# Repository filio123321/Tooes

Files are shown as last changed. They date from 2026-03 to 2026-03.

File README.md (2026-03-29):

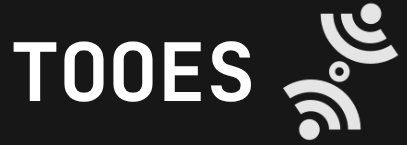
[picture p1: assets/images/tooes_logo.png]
TOOES
# 

Tooes is a Raspberry Pi-based passive RF navigation prototype. The firmware
listens to broadcast cellular signals, resolves observed towers against a local
OpenCellID database, and fuses the RF fixes with IMU dead-reckoning to track
position on a small e-paper map display.

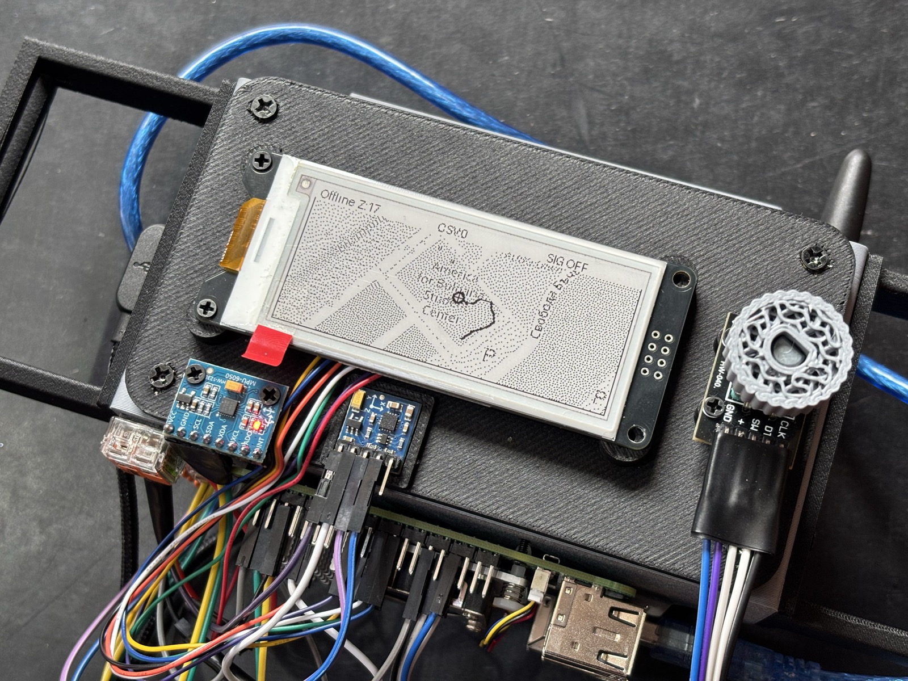
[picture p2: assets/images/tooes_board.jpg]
A photo of the TOOES project build


## What The Repo Does Today

- The main app starts from a known GPS coordinate (`INITIAL_L`), tracks
  short-range movement with the MPU-6050 accelerometer and QMC5883L
  magnetometer, and blends in periodic SDR-based position fixes as the user
  moves. The fused path is rendered live on the e-paper display.
- A walking sweep POC performs 2D dead-reckoning from accelerometer data and
  magnetometer heading and visualises the path and RSSI bars in a desktop
  Pygame window. It does not use the MPU-6050 gyroscope.
- The radio path implements the GSM `grgsm_scanner` flow. LTE protocol-specific
  work can be added later without changing the top-level documentation
  structure.

## Documentation

- [System architecture](docs/architecture.md)
- [Hardware and wiring](docs/hardware.md)
- [Motion estimation math](docs/algorithms/motion-estimation.md)
- [RF localization pipeline](docs/algorithms/rf-localization.md)
- [Raspberry Pi setup and operations](docs/operations/pi-setup.md)
- [Experiments and proof-of-concepts](docs/experiments.md)
- [Firmware-specific reference](firmware/README.md)

## Repository Layout

- `firmware/` — Raspberry Pi firmware: HAL, navigation engine, runtime
  orchestrator, UI, scripts, and tests.
- `firmware/navigation/` — navigation engine: IMU sample processing, SDR fix
  blending, trace logging, and configuration.
- `firmware/runtime/` — background threading: orchestrator and navigation
  worker that feed the UI.
- `signal_processing/` — SDR positioning algorithms (trilateration, Kalman
  filter, RF-IMU fusion). Experimental.
- `scripts/` — repo-level utilities including the Pi setup script.
- `external/waveshare-epd/` — Waveshare e-paper driver submodule.
- `assets/` — 3D-printable hardware assets.
- `separate_component_files/` — standalone experiments and component-specific
  utilities.

## Quick Start

### 1. Run the test suite

```bash
python -m pytest firmware/tests/ -v
```

### 2. Exercise the mock or replay RF path without Pi hardware

```bash
HAL_BACKEND=replay HAL_REPLAY_PATH=firmware/tests/fixtures/golden_sweep.jsonl \
python -c "from firmware.hal import get_sweep_source; print(list(get_sweep_source())[:2])"
```

### 3. Deploy and run on the Raspberry Pi

See [docs/operations/pi-setup.md](docs/operations/pi-setup.md) for the full
guide. The short version:

```bash
# From your laptop — syncs code, configures I2C, sets up git for future pulls:
PI_PASS=<password> bash scripts/setup_pi.sh [user@host]

# Then on the Pi — install dependencies and set your starting location:
pip3 install --break-system-packages -r firmware/requirements.txt

cat > .env.local <<'EOF'
INITIAL_L=42.012280,23.095261
EOF

# Launch the app:
HAL_BACKEND=grgsm \
HAL_ROTATION=qmc5883l \
HAL_ACCEL=mpu6050 \
HAL_GRGSM_SCANNER_CMD="grgsm_scanner -b GSM900 -a 'driver=sdrplay'" \
python3 -m firmware.run
```

`INITIAL_L` is the absolute starting point used by the navigation engine. The
app then tracks IMU-based relative movement locally and periodically blends in
SDR fixes as it moves away from the last anchor.

While running, the fused path is written to
`firmware/logs/navigation_trace_*.jsonl` unless you set
`NAV_PATH_LOG_ENABLED=false`.

## Required Runtime Assets

- `external/waveshare-epd/` must be populated with
  `git submodule update --init --recursive` before the e-paper display path
  can import the Waveshare driver.
- `firmware/data/<mcc>.csv` must exist locally for any country code you want
  to resolve through OpenCellID. These files are intentionally not committed.
- `firmware/offline_tiles/` is optional but required for the map view to
  render real offline tiles instead of placeholders.

## Important Notes

- The absolute position estimate in the main app is not true trilateration.
  The current implementation is a heuristic RSSI-weighted centroid over the
  resolved towers, used as a periodic correction anchor for the IMU track.
- The motion stack is currently accelerometer plus magnetometer; gyroscope
  fusion is not yet implemented.
- The repo contains both product code and experiments. See
  [docs/experiments.md](docs/experiments.md) for the current boundary.

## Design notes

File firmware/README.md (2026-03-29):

# firmware/

Firmware-specific reference for the Raspberry Pi application, HAL backends, and
supporting scripts.

For project-wide documentation, start at:

- `README.md`
- `docs/architecture.md`
- `docs/algorithms/motion-estimation.md`
- `docs/algorithms/rf-localization.md`

Python code that runs on the Raspberry Pi (or a laptop during development):
GSM cell observation via `grgsm_scanner` + SoapySDR, OpenCellID tower lookup,
IMU dead-reckoning with SDR fix blending, and e-ink display output.

## Project structure

```
firmware/
├── hal/                       # Hardware Abstraction Layer
│   ├── __init__.py            # Public API: protocols, types, factory getters
│   ├── types.py               # CellKey, SweepSample dataclasses + JSON (de)serialization
│   ├── protocols.py           # SweepSampleSource, RotationReader, CellRssiReader,
│   │                          #   TiltReader, AccelerationReader, DisplaySink
│   ├── mock.py                # MockSweepSource — deterministic synthetic sweep
│   ├── mock_cells.py          # MockCellRssiReader — position-dependent fake RSSI
│   ├── replay.py              # JsonlReplaySource — replay a recorded .jsonl sweep file
│   ├── grgsm_scanner.py       # Parse grgsm_scanner stdout, GrgsmCellReader adapter
│   ├── factory.py             # Env-driven factories: get_sweep_source(), get_rotation_reader(),
│   │                          #   get_tilt_reader(), get_accel_reader(), get_cell_reader()
│   ├── dead_reckoning.py      # DeadReckoningTracker — ZUPT-based position tracking
│   ├── qmc5883l.py            # QMC5883L magnetometer RotationReader (real hardware, I2C)
│   ├── mpu6050.py             # MPU-6050 TiltReader + AccelerationReader (I2C)
│   └── _stub_rotation.py     # Stubs: StubRotationReader, StubTiltReader, StubAccelerationReader
│
├── navigation/                # Navigation engine (IMU + SDR fusion)
│   ├── config.py              # NavigationConfig — loads .env.local and env vars
│   ├── service.py             # NavigationEngine — fuses IMU + SDR, emits NavigationSnapshot
│   ├── imu.py                 # ImuSampleProcessor — step detection + dead-reckoning
│   ├── sdr.py                 # SdrFixProvider — schedules SDR fixes, computes confidence
│   ├── geo.py                 # Distance and bearing helpers
│   ├── path_logger.py         # Writes navigation trace to JSONL
│   └── trace.py               # In-memory trace point history
│
├── runtime/                   # Background threading and orchestration
│   ├── orchestrator.py        # FirmwareOrchestrator — owns sensor threads, exposes snapshot()
│   └── navigation_worker.py   # Navigation update loop running at IMU_UPDATE_HZ
│
├── ui/                        # E-ink display UI
│   ├── app.py                 # Entry point — inits display, encoder, button; runs event loop
│   ├── runtime.py             # Bridges app.py with FirmwareOrchestrator
│   ├── state.py               # UiState, RuntimeSnapshot, DiscoveredTower dataclasses
│   ├── screens.py             # Screen renderers: BOOT, TUTORIAL, SCANNING, MAP
│   ├── redraw.py              # Decides when a full e-paper refresh is needed
│   ├── geo.py                 # Geographic utilities (zoom, coordinate clamping)
│   ├── tiles.py               # Offline OSM tile rendering
│   └── icons.py               # UI icon definitions
│
├── tests/
│   ├── fixtures/
│   │   └── golden_sweep.jsonl # 20-sample fixture generated from MockSweepSource
│   ├── test_hal.py            # pytest suite for the HAL
│   ├── test_navigation.py     # pytest suite for the navigation engine
│   └── test_ui_redraw.py      # pytest suite for redraw logic
│
├── data/
│   └── 284.csv                # OpenCellID tower database for MCC 284 (Bulgaria)
│
├── logs/                      # Navigation trace logs (gitignored, created at runtime)
│
├── scripts/
│   ├── orientation_cube.py    # 3D cube visualisation of sensor orientation (Pi desktop)
│   ├── sweep_poc.py           # Walking-sweep POC with dead reckoning + live map/RSSI viz
│   └── install_tiles.py       # Download offline OSM tiles for the e-ink map
│
├── opencellid.py              # lookup_tower(mcc, mnc, lac, cell_id) → (lat, lon)
├── tower_data.py              # CatalogTower dataclass + OpenCellID CSV parsing
├── log_config.py              # Shared logging setup
├── run.py                     # Main entry point — imports firmware.ui.app
└── requirements.txt           # Pi runtime dependencies
```

## Running tests

Tests use **pytest** and have no hardware dependencies.

```bash
# From the repo root:
python -m pytest firmware/tests/ -v
```

pytest is configured in the top-level `pyproject.toml`:

```toml
[tool.pytest.ini_options]
testpaths = ["firmware/tests"]
```

Install the dev dependency if needed:

```bash
pip install pytest
```

## HAL backends

The HAL is selected at runtime via the `HAL_BACKEND` environment variable:

| `HAL_BACKEND` | What it does | Extra env vars |
|---|---|---|
| `mock` (default) | Deterministic synthetic 360-degree sweep | — |
| `replay` | Replays a recorded JSONL file | `HAL_REPLAY_PATH` — path to `.jsonl` file |
| `grgsm` | Runs `grgsm_scanner` (SoapySDR) as a subprocess | `HAL_GRGSM_SCANNER_CMD` — full shell command |

Example — replay a previously recorded sweep:

```bash
HAL_BACKEND=replay HAL_REPLAY_PATH=firmware/tests/fixtures/golden_sweep.jsonl \
  python -c "from firmware.hal import get_sweep_source; print(list(get_sweep_source()))"
```

## JSONL format

Each line in a `.jsonl` sweep file is a self-contained JSON object:

```json
{"schema_version": 1, "t": 0.0, "azimuth_deg": 0.0, "cells": [{"mcc": 284, "mnc": 1, "lac": 1000, "ci": 101, "rssi_dbm": -50.0}]}
```

The `schema_version` field guards against silent format drift between the
recorder and the replay/localization code.

## Component factories

All sensor backends are selected at runtime via environment variables:

### Rotation (`HAL_ROTATION`)

| Value | What it does |
|---|---|
| `stub` (default) | Increments azimuth by a fixed step each call (no hardware) |
| `qmc5883l` | Reads heading from a QMC5883L magnetometer over I2C (GY-271 board) |

### Tilt (`HAL_TILT`)

| Value | What it does |
|---|---|
| `stub` (default) | Always returns pitch=0, roll=0 |
| `mpu6050` | Reads pitch/roll from MPU-6050 accelerometer (I2C) |

### Acceleration (`HAL_ACCEL`)

| Value | What it does |
|---|---|
| `stub` (default) | Returns (0, 0, 1g) — stationary, gravity down |
| `mpu6050` | Reads 3-axis acceleration from MPU-6050 (I2C) |

### Cell reader (`HAL_CELLS`)

| Value | What it does | Extra env vars |
|---|---|---|
| `mock` (default) | Position-dependent fake RSSI from 3 virtual towers | — |
| `grgsm` | Runs `grgsm_scanner` subprocess | `HAL_GRGSM_SCANNER_CMD` |

### Trigger distance (`HAL_TRIGGER_DISTANCE`)

Distance in metres between automatic measurements in the sweep POC (default: `2.0`).

### Wiring

**GY-271 (QMC5883L)** — verify at `0x0d` with `i2cdetect -y 1`:

| GY-271 pin | Pi 5 physical pin | Function |
|---|---|---|
| VCC | Pin 1 | 3.3V (**not** 5V) |
| GND | Pin 6 | Ground |
| SDA | Pin 3 | GPIO 2 (I2C1 SDA) |
| SCL | Pin 5 | GPIO 3 (I2C1 SCL) |

**MPU-6050** — verify at `0x68` with `i2cdetect -y 1`:

| MPU-6050 pin | Pi 5 physical pin | Function |
|---|---|---|
| VCC | Pin 1 | 3.3V |
| GND | Pin 6 | Ground |
| SDA | Pin 3 | GPIO 2 (I2C1 SDA) |
| SCL | Pin 5 | GPIO 3 (I2C1 SCL) |

## Deploying to the Raspberry Pi

The Pi is at `team@tooes.local` (or `team@10.15.86.130` as fallback).

### 1. Run the setup script (first time)

From your laptop at the repo root:

```bash
PI_PASS=<password> bash scripts/setup_pi.sh [user@host]
```

This rsyncs the repo, initialises a git repo on the Pi, adds the GitHub
remote, checks out `main`, enables I2C, and installs `i2c-tools` + `smbus2`.

Requires `sshpass`:

```bash
apt install sshpass
```

### 2. Install Python dependencies

```bash
ssh team@tooes.local
cd ~/Tooes
pip3 install --break-system-packages -r firmware/requirements.txt
```

### 3. Initialise the Waveshare submodule

On the Pi after the initial sync:

```bash
cd ~/Tooes
git submodule update --init --recursive
```

### 4. Sync the OpenCellID data (not in git)

The `firmware/data/` directory contains large CSV files from OpenCellID and is
excluded from git. The setup script syncs it automatically if the directory
exists locally. To re-sync manually:

```bash
# From your laptop, at the repo root:
rsync -avz --progress firmware/data/ team@tooes.local:~/Tooes/firmware/data/
```

### 5. Create `.env.local`

```bash
ssh team@tooes.local
cd ~/Tooes
cat > .env.local <<'EOF'
INITIAL_L=42.012280,23.095261
EOF
```

Replace the coordinates with your actual starting location.

### 6. Pull code updates (subsequent deploys)

```bash
ssh team@tooes.local "cd ~/Tooes && git pull"
```

### 7. Run with real hardware

```bash
ssh team@tooes.local
cd ~/Tooes

HAL_BACKEND=grgsm \
  HAL_ROTATION=qmc5883l \
  HAL_ACCEL=mpu6050 \
  HAL_GRGSM_SCANNER_CMD="grgsm_scanner -b GSM900 -a 'driver=sdrplay'" \
  python3 -m firmware.run
```

The runtime starts from `.env.local` via `INITIAL_L=lat,lon`, tracks
short-range movement with the MPU-6050, and uses SDR fixes as periodic anchor
corrections. The fused trace is written to
`firmware/logs/navigation_trace_*.jsonl` by default.

### 8. Walking-sweep POC (mock radio + real sensors)

Run on the Pi desktop to visualise dead-reckoning position + RSSI bars.
Press **Space** for a manual measurement, or walk ≥ `HAL_TRIGGER_DISTANCE`
metres for an automatic one.

```bash
# All stubs (desktop testing on a laptop without sensors):
python3 firmware/scripts/sweep_poc.py

# Real sensors + mock radio on the Pi:
HAL_ROTATION=qmc5883l HAL_TILT=mpu6050 HAL_ACCEL=mpu6050 \
  HAL_CELLS=mock HAL_TRIGGER_DISTANCE=2.0 \
  python3 firmware/scripts/sweep_poc.py
```

The window is split into a 2D path map (left) and a live RSSI bar chart (right).
Tower triangles show the virtual tower positions used by the mock cell reader.

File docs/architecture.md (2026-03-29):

# Architecture

This document describes how the current codebase is structured and how data
flows through it. It is intentionally grounded in the code that exists today,
not in the longer-term vision for the project.

## System Overview

The repository has two main runtime paths:

1. The e-paper application, started via `python3 -m firmware.run`, which fuses
   IMU dead-reckoning with periodic SDR fixes and renders a map UI on the
   Raspberry Pi.
2. The walking proof-of-concept in `firmware/scripts/sweep_poc.py`, which uses
   motion sensors and periodic cell measurements to visualise a relative path
   and live RSSI values on a desktop window.

Both paths are built on top of the HAL in `firmware/hal/`, which provides
small protocol interfaces and environment-driven factories for selecting real,
mock, or replay backends.

## Core Data Model

Two data structures connect almost all RF-related components:

- `CellKey` in `firmware/hal/types.py`
  - identifies a cell observation as `(mcc, mnc, lac, ci)`
- `SweepSample` in `firmware/hal/types.py`
  - stores one observation instant as:
    - elapsed time `t`
    - current azimuth `azimuth_deg`
    - `cells: Dict[CellKey, float]`

The serialised JSONL format uses the same structure, which makes the replay
path and the live path share the same downstream logic.

## HAL Layer

The HAL protocols in `firmware/hal/protocols.py` define the minimum contracts
used by the rest of the code:

- `SweepSampleSource`
- `RotationReader`
- `CellRssiReader`
- `TiltReader`
- `AccelerationReader`

The factory module `firmware/hal/factory.py` maps environment variables to
concrete implementations:

- RF sweep source: `mock`, `replay`, `grgsm`
- Rotation reader: `stub`, `qmc5883l`
- Tilt reader: `stub`, `mpu6050`
- Acceleration reader: `stub`, `mpu6050`
- Cell reader: `mock`, `grgsm`

This arrangement makes the same app logic usable against both real hardware
and deterministic development backends.

## Navigation Engine (`firmware/navigation/`)

The `firmware/navigation/` package is the core positioning logic. It was
introduced as part of the component-integration refactor that unified the
previously separate UI and sensor threads.

Key components:

- `config.py` — `NavigationConfig` dataclass loaded from `.env.local` and
  environment variables. Controls IMU update rate, step detection thresholds,
  SDR blending weights, and trace logging. See
  `docs/operations/pi-setup.md` for the full list of settable variables.
- `service.py` — `NavigationEngine`. The main fusion loop. Accepts IMU samples
  from `ImuSampleProcessor` and SDR fixes from `SdrFixProvider`, and emits
  `NavigationSnapshot` objects with current `(lat, lon)`, heading, trace
  history, and SDR confidence.
- `imu.py` — `ImuSampleProcessor`. Reads raw accelerometer and magnetometer
  samples, runs step detection, and converts relative displacement into
  geographic increments.
- `sdr.py` — `SdrFixProvider`. Schedules periodic SDR measurements and
  computes a confidence-weighted geographic fix to blend into the IMU track.
- `geo.py` — distance and bearing helpers used by the navigation engine.
- `path_logger.py` — writes the fused navigation trace to a JSONL file.
- `trace.py` — manages the in-memory trace point history.

## Runtime Orchestrator (`firmware/runtime/`)

The `firmware/runtime/` package owns the background threads and produces the
`RuntimeSnapshot` that the UI consumes.

- `orchestrator.py` — `FirmwareOrchestrator`. Starts the navigation worker
  thread and the scan thread, protects shared state with a lock, and exposes
  a single non-blocking `snapshot()` call that the UI polls on each render
  cycle.
- `navigation_worker.py` — the navigation update loop. Reads IMU sensors at
  the configured rate (`IMU_UPDATE_HZ`, default 50 Hz), feeds
  `NavigationEngine`, and pushes updated `RuntimeSnapshot` objects into the
  orchestrator's queue.

### Thread model

```
main thread (UI event loop)
    │
    ├── calls orchestrator.snapshot() on each frame
    │
    └── FirmwareOrchestrator
            ├── navigation thread  ← runs at IMU_UPDATE_HZ (50 Hz default)
            │       reads MPU-6050 + QMC5883L → NavigationEngine
            │       pushes RuntimeSnapshot into a maxsize-1 queue
            │
            └── scan thread (on demand)
                    runs grgsm_scanner subprocess
                    resolves towers via OpenCellID CSV
                    updates tower list in RuntimeSnapshot
```

The `RuntimeSnapshot` published by the orchestrator is a frozen dataclass, so
the UI thread never needs to acquire a lock to read it.

## RF Discovery Pipeline

The current RF path is layered like this:

1. **Capture and parsing** — `firmware/hal/grgsm_scanner.py` runs
   `grgsm_scanner` and parses stdout into `CellKey -> RSSI` maps.
2. **Sweep assembly** — `GrgsmScannerSource` pairs each parsed RF snapshot
   with a heading from a `RotationReader`, producing a `SweepSample`.
3. **Tower resolution** — `firmware/opencellid.py` looks up each `CellKey`
   in a local OpenCellID CSV file named after the mobile country code.
4. **Aggregation** — the scan thread keeps the strongest observed RSSI per
   tower and assigns human-readable labels such as `T1`, `T2`, `T3`.
5. **Position estimate** — after scanning completes, a heuristic
   RSSI-weighted centroid is computed from the resolved towers.

## Main E-Paper App

The e-paper application entry point is `firmware/run.py`, which delegates to
`firmware/ui/app.py`. The UI layer is split into focused modules:

- `app.py` — initialises the display, rotary encoder, and button; starts the
  orchestrator; runs the event loop.
- `runtime.py` — bridges `app.py` with `FirmwareOrchestrator`.
- `state.py` — `UiState`, `RuntimeSnapshot`, and `DiscoveredTower` dataclasses
  (frozen, safe to pass across thread boundaries).
- `screens.py` — rendering functions for each screen: `BOOT`, `TUTORIAL`,
  `SCANNING`, `MAP`.
- `redraw.py` — decides when a full e-paper refresh is warranted to avoid
  unnecessary redraws on the slow display.

The four UI screens are:

- `BOOT` — splash screen shown during startup
- `TUTORIAL` — one-time usage hint pages
- `SCANNING` — progress indicator while the first scan runs
- `MAP` — map view with trace overlay, heading arrow, and tower markers

The trace overlay is enabled by default and shows the recent navigation path
on the map.

## Walking POC Architecture

The desktop POC in `firmware/scripts/sweep_poc.py` uses a different structure
from the e-paper app:

1. get a rotation reader and acceleration reader
2. construct a `DeadReckoningTracker`
3. construct a `CellRssiReader` using the tracker position
4. repeatedly update relative position `(x, y)` in metres
5. trigger a cell measurement when the operator walks at least
   `HAL_TRIGGER_DISTANCE` metres or presses Space
6. render the path, heading, tower layout, and RSSI bars in Pygame

This path produces a local relative coordinate frame, not a geographic
latitude/longitude estimate.

## Position Outputs

The repo currently has two distinct notions of "position":

- **Absolute geographic estimate** in the main app — a fused
  latitude/longitude that starts from `INITIAL_L` and is continuously updated
  by IMU dead-reckoning with periodic SDR-based anchor corrections.
- **Relative local estimate** in the walking POC — dead-reckoned `(x, y)`
  coordinates in metres from the starting point.

These should not be treated as the same output.

## Navigation Trace Logging

The main app writes the fused navigation path to a JSONL file under
`firmware/logs/` by default. Each line records a timestamped `(lat, lon)`
checkpoint. This log is useful for post-session analysis and replay testing.

Control it with:

```
NAV_PATH_LOG_ENABLED=true          # default; set to false to disable
NAV_PATH_LOG_PATH=firmware/logs/my_trace.jsonl  # optional custom path
```

## Offline Assets And External Boundaries

Several pieces of runtime behaviour depend on assets or tools not managed by
the Python package itself:

- `external/waveshare-epd/` — git submodule used by the e-paper display path
- `firmware/data/` — local OpenCellID CSV files, not committed
- `firmware/offline_tiles/` — optional offline OpenStreetMap tile cache
- `grgsm_scanner`, SoapySDR, and SDR-specific drivers — external system
  dependencies for the live GSM path

## Current Algorithmic Truths

The documentation should stay aligned with these implementation facts:

- the main app does not currently perform true trilateration or multilateration
- the motion stack does not currently use gyroscope integration or IMU fusion
- the dead-reckoning path is a lightweight POC, not a navigation-grade motion
  solution
- the RF stack is currently GSM-specific at the parser and identity layer

## Extension Points For LTE And Richer SDR Work

The cleanest way to grow the documentation when LTE support is added is to keep
the current layered structure and swap in richer detail at the protocol layer:

- **capture layer** — current: `grgsm_scanner`; future: richer SDR capture
  paths, LTE-specific tools, or direct SDR APIs
- **identity layer** — current: `CellKey(mcc, mnc, lac, ci)`; future: LTE
  identifiers such as TAC, ECI, PCI, EARFCN
- **geolocation layer** — current: local CSV lookup; future: same conceptual
  layer, possibly with additional tower datasets
- **positioning layer** — current: heuristic centroid; future: calibrated RF
  propagation models, multilateration, filtering, or fusion with motion
  estimates

This is why the algorithm docs are split into separate motion and RF documents:
the system will grow, but the high-level architecture can stay stable.

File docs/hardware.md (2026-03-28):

# Hardware And Wiring

This document collects the hardware assumptions currently encoded in the repo.
It covers what the code expects today, how the main sensors are wired, and
which dependencies are external to the Python code.

## Hardware In The Current Repo

### Raspberry Pi

The current firmware targets a Raspberry Pi and assumes:

- Python 3 is available
- I2C is enabled
- GPIO access is available
- the process can talk to the display driver and sensors

### Display

The main app imports the Waveshare 2.9 inch display driver from the git
submodule:

- `external/waveshare-epd/RaspberryPi_JetsonNano/python/lib`

The display code currently expects `waveshare_epd.epd2in9_V2`.

Important note:

- the submodule is declared in `.gitmodules`, but it may not be populated in a
  fresh checkout
- run:

```bash
git submodule update --init --recursive
```

before attempting to launch the real e-paper UI

### Rotary Encoder

The main app uses an HW-040 style rotary encoder on these BCM pins:

- `CLK`: BCM 5
- `DT`: BCM 6
- `SW`: BCM 13

These values are hard-coded in `firmware/ui/app.py`.

### Magnetometer: QMC5883L / GY-271

The heading path uses a QMC5883L magnetometer over I2C.

Expected address:

- `0x0d`

Wiring:

| GY-271 pin | Pi physical pin | Function |
| --- | --- | --- |
| VCC | Pin 1 | 3.3V |
| GND | Pin 6 | Ground |
| SDA | Pin 3 | GPIO 2 / I2C1 SDA |
| SCL | Pin 5 | GPIO 3 / I2C1 SCL |

Verification:

```bash
i2cdetect -y 1
```

The device should appear at `0x0d`.

### Accelerometer: MPU-6050

The tilt and acceleration path uses the accelerometer half of the MPU-6050.
The current code does not read the gyroscope registers.

Expected address:

- `0x68` by default
- `0x69` if AD0 is pulled high

Wiring:

| MPU-6050 pin | Pi physical pin | Function |
| --- | --- | --- |
| VCC | Pin 1 | 3.3V |
| GND | Pin 6 | Ground |
| SDA | Pin 3 | GPIO 2 / I2C1 SDA |
| SCL | Pin 5 | GPIO 3 / I2C1 SCL |

Verification:

```bash
i2cdetect -y 1
```

The device should appear at `0x68` unless the board wiring changes the address.

### SDR And GSM Scan Path

The live RF path expects an external GSM scanner command. The code currently
assumes `grgsm_scanner` and a working SoapySDR-compatible radio chain. Those
pieces are not installed or configured by the Python package itself.

In practice this means:

- the SDR hardware choice lives outside this repo
- the exact scanner command is supplied via `HAL_GRGSM_SCANNER_CMD`
- radio drivers, SoapySDR, GNU Radio dependencies, and scan permissions are
  system concerns

## Python And System Dependencies

The current runtime dependency file is `firmware/requirements.txt`:

- `requests`
- `Pillow`
- `gpiozero`
- `spidev`
- `RPi.GPIO`
- `smbus2`

Important operational note:

- `scripts/setup_pi.sh` currently enables I2C and installs `smbus2`, but it
  does not install the entire Python dependency set or the radio stack

For the Pi runtime, an explicit install step is still recommended:

```bash
pip3 install --break-system-packages -r firmware/requirements.txt
```

## Data Dependencies

### OpenCellID CSVs

Tower lookup depends on local CSV files in:

- `firmware/data/`

The lookup code searches for a file named after the MCC, for example:

- `firmware/data/284.csv`

These files are intentionally not committed. If the file is missing,
`firmware/opencellid.py` exits with a fatal error.

### Offline Map Tiles

The map renderer loads PNG tiles from:

- `firmware/offline_tiles/`

If tiles are missing, the app still runs, but it draws placeholder tiles with
`z/x/y` labels instead of a real map.

The tile preloader is:

- `firmware/scripts/install_tiles.py`

## Current Hardware Assumptions In The Math

The motion and heading code assume:

- the device is held roughly level
- the QMC5883L Z axis points upward
- pitch and roll are small enough that simple tilt compensation is usable
- the motion code can treat the horizontal accelerometer axes as meaningful
  horizontal acceleration

These assumptions are good enough for a prototype, but they should not be
mistaken for a calibrated inertial navigation stack.

## Known Gaps

- No explicit magnetometer calibration procedure is implemented.
- No accelerometer calibration procedure is implemented.
- No gyroscope path is wired into the current motion estimator.
- No single document in code defines the physical sensor mounting frame beyond
  comments and formulas.
- No automated setup in the repo currently installs `grgsm_scanner`, GNU Radio,
  or SoapySDR-related tooling.

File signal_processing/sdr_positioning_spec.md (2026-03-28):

# SDR Positioning System — Complete Technical Specification

Module structure · AGC · Attenuation · Trilateration · Kalman | 2026-03-28

---

## 1. Module Structure

The entire project is a single Python package: `sdr_positioning/`. Nothing outside it needs to know about SoapySDR, gain values, or signal physics.

```
sdr_positioning/
    __init__.py              # public API: PositioningSystem
    sdr_module/              # hardware abstraction
        __init__.py          # public: SDRModule, Measurement, CatalogueEntry
        catalogue.py         # CatalogueLoader
        receiver.py          # SDRReceiver (SoapySDR wrapper — only file that imports SoapySDR)
        agc.py               # GainController
    trilateration.py         # attenuation model + trilateration solver
    kalman.py                # KalmanFilter + coordinate helpers
    fusion.py                # FusionEngine (owns Kalman + sources)
    models.py                # shared dataclasses: Measurement, PositionEstimate
    stations.json            # signal catalogue (ships with module)
```

**Dependency rule — imports flow in one direction only:**

| File | May import from |
|---|---|
| `sdr_module/*` | Standard library + numpy + SoapySDR only |
| `trilateration.py` | sdr_module, models, numpy, scipy |
| `kalman.py` | models, numpy |
| `fusion.py` | trilateration, kalman, models, sdr_module |
| `__init__.py` | fusion only (exposes PositioningSystem) |

> `models.py` exists to break circular imports. All shared dataclasses live there. No file imports from `fusion.py` except `__init__.py`.

**External usage — the entire system in 5 lines:**

```python
from sdr_positioning import PositioningSystem

ps = PositioningSystem("sdr_positioning/stations.json")
ps.feed_imu(ax=0.1, ay=0.0, heading_deg=45., dt=0.02)
estimate = ps.step()   # returns PositionEstimate | None
```

---

## 2. Shared Dataclasses (models.py)

```python
from dataclasses import dataclass, field
import time

@dataclass
class Measurement:
    source_id:        str
    rssi_dbm:         float   # normalised: measured_power - gain_used
    freq_hz:          float
    signal_type:      str
    lat:              float   # transmitter position
    lon:              float
    power_w:          float   # transmitter ERP in watts
    gain_used:        float   # dB — for diagnostics
    antenna_gain_dbi: float = 0.0
    best_effort:      bool  = False
    timestamp:        float = field(default_factory=time.time)

@dataclass
class PositionEstimate:
    lat:          float
    lon:          float
    accuracy_m:   float   # 1-sigma radius
    speed_ms:     float
    heading_deg:  float
    source:       str     # "IMU" | "RF_UPDATE"
    n_rf_sources: int
    last_rf_age:  float   # seconds since last RF update
    timestamp:    float = field(default_factory=time.time)
```

> `Measurement` carries the transmitter `lat`/`lon` and `power_w` so that `trilateration.py` does not need to re-query the catalogue. The catalogue lookup happens once in `sdr_module`, not twice.

---

## 3. Signal Catalogue (catalogue.py)

### 3.1 JSON Schema

The existing station JSON is the canonical format. Key is frequency in MHz as string:

```json
{
  "91.4": {
    "lat": 42.035704,  "lon": 23.095343,
    "station": "РРС Благоевград",
    "name": "БГ Радио",
    "type": "FM",
    "power_w": 300
  },
  "506.0": {
    "lat": 42.6635,  "lon": 23.2946,
    "station": "Витоша предавател",
    "name": "БНТ 1",
    "type": "DVB-T",
    "power_w": 10000,
    "antenna_gain_dbi": 6.0
  }
}
```

### 3.2 Type Defaults Registry

| type | freq range MHz | antenna_gain_dbi | min_rssi_dbm |
|---|---|---|---|
| FM | 87.5–108 | 0.0 | −90 |
| VOR | 108–118 | 0.0 | −90 |
| DAB | 174–240 | 0.0 | −95 |
| DVB-T | 470–862 | 6.0 | −95 |
| GSM | 935–960 | 9.0 | −95 |

`antenna_gain_dbi` in the JSON overrides the type default. `power_w` is always required.

### 3.3 CatalogueEntry Dataclass

```python
@dataclass(frozen=True)
class CatalogueEntry:
    source_id:        str    # e.g. "FM_91.4_Blagoevgrad"
    freq_hz:          float  # "91.4" -> 91.4e6
    lat:              float
    lon:              float
    station:          str
    name:             str
    signal_type:      str
    power_w:          float
    antenna_gain_dbi: float
    min_rssi_dbm:     float
    max_rssi_dbm:     float = -20.0
```

---

## 4. SDR Module (sdr_module/)

### 4.1 SDRReceiver

Thin SoapySDR wrapper. The only file in the project that imports SoapySDR.

```python
class SDRReceiver:
    def set_gain(self, gain_db: float) -> None
    def set_freq(self, freq_hz: float) -> None
    def set_sample_rate(self, rate_hz: float) -> None
    def read_power_dbm(self, n_samples=4096) -> float
        # IQ capture -> Hanning window -> FFT -> mean power in dBm
    def close(self) -> None
```

### 4.2 Adaptive Gain Control

The AGC produces calibrated RSSI readings by finding the optimal gain for each signal type and normalising out the gain applied.

#### Normalisation — the one formula

```
true_power_dbm = measured_power_dbm − gain_db
```

`measured_power_dbm` is what `read_power_dbm()` returns. `gain_db` is what was set on the receiver. `true_power_dbm` is what `Measurement.rssi_dbm` contains. This formula appears exactly once in `GainController.measure()`.

#### Per-type gain strategy

| Signal type | Target window (dBm) | Start gain (dB) | Step size (dB) |
|---|---|---|---|
| FM | −55 to −75 | 50 | 10 |
| VOR | −65 to −85 | 70 | 10 |
| DAB | −60 to −80 | 60 | 10 |
| DVB-T | −55 to −75 | 55 | 10 |
| GSM | −35 to −55 | 20 | 10 |

**Algorithm:** set `start_gain`, read power, compute `true_power = measured - gain`. If `true_power` is outside the target window, adjust gain by `(window_midpoint - measured)` and retry. Max 4 steps. Return best-effort result if gain never fully settles.

> Gain is reset to `start_gain` between signal types. GSM at gain=20 must not bleed into VOR which needs gain=70.

```python
class GainController:
    MAX_STEPS = 4
    GAIN_MIN  = 0.
    GAIN_MAX  = 80.

    def measure(self, entry: CatalogueEntry,
                receiver: SDRReceiver) -> Measurement | None:
        strategy = GAIN_STRATEGIES[entry.signal_type]
        gain = strategy.start_gain
        receiver.set_freq(entry.freq_hz)
        receiver.set_sample_rate(2e6)

        for step in range(self.MAX_STEPS):
            receiver.set_gain(gain)
            p_measured = receiver.read_power_dbm()
            p_true     = p_measured - gain

            if p_true < entry.min_rssi_dbm:
                return None  # signal too weak, below noise floor

            if p_true > entry.max_rssi_dbm:
                return None  # signal too strong, near-field

            lo, hi = strategy.target_window
            if lo <= p_measured <= hi:
                return Measurement(
                    source_id   = f"{entry.signal_type}_{entry.freq_hz/1e6}",
                    rssi_dbm    = p_true,
                    gain_used   = gain,
                    freq_hz     = entry.freq_hz,
                    signal_type = entry.signal_type,
                    lat         = entry.lat,
                    lon         = entry.lon,
                    power_w     = entry.power_w,
                    antenna_gain_dbi = entry.antenna_gain_dbi,
                )

            midpoint = (lo + hi) / 2
            gain    += (midpoint - p_measured)
            gain     = max(self.GAIN_MIN, min(self.GAIN_MAX, gain))

        # Best effort — return last values
        return Measurement(
            source_id   = f"{entry.signal_type}_{entry.freq_hz/1e6}",
            rssi_dbm    = p_true,
            gain_used   = gain,
            freq_hz     = entry.freq_hz,
            signal_type = entry.signal_type,
            lat         = entry.lat,
            lon         = entry.lon,
            power_w     = entry.power_w,
            antenna_gain_dbi = entry.antenna_gain_dbi,
            best_effort = True,
        )
```

### 4.3 SDRModule Public API

```python
class SDRModule:
    def __init__(self, catalogue_path, driver="sdrplay", serial=None)
    def scan(self, types=None) -> list[Measurement]
        # Scans catalogue entries, returns normalised Measurements
        # Measurement already contains transmitter lat/lon/power_w
    def close(self)
```

### 4.4 Recommended Scan Order

| Order | Signal type | Reason |
|---|---|---|
| 1 | FM (87–108 MHz) | Strongest, most reliable. Sets initial environment class. |
| 2 | VOR (108–118 MHz) | Adjacent band — cheap re-tune from FM. |
| 3 | DAB (174–240 MHz) | Medium band. Good geometry supplement to FM. |
| 4 | DVB-T (470–862 MHz) | High power broadcast. Good GDOP filler. |
| 5 | GSM (935–960 MHz) | Low gain required. Scan last to avoid AGC disruption. |

---

## 5. Attenuation Model (trilateration.py)

Converts `Measurement.rssi_dbm` into an estimated distance in metres. Every physical parameter is explicit.

### 5.1 Free-Space Path Loss

The received power at distance `d` from a transmitter:

```
EIRP_dbm  = 10·log10(power_w) + 30 + antenna_gain_dbi
FSPL_dB   = 20·log10(d) + 20·log10(freq_hz) − 147.55
RSSI_pred = EIRP_dbm − FSPL_dB
```

The constant `−147.55 = 20·log10(4π/c)` where `c = 3×10⁸ m/s`. It embeds wavelength: `λ = c/f`, so higher frequency = shorter wavelength = more FSPL. No separate wavelength correction is needed.

### 5.2 Inverting for Distance

```
path_loss_dB = EIRP_dbm − rssi_dbm
d_freespace  = 10^((path_loss_dB + 147.55 − 20·log10(freq_hz)) / 20)
```

### 5.3 Frequency Effect

| Signal type | Frequency | Extra FSPL vs FM 100 MHz at same distance |
|---|---|---|
| FM | 100 MHz | 0 dB (reference) |
| VOR | 113 MHz | +1.1 dB |
| DAB | 200 MHz | +6.0 dB |
| DVB-T | 650 MHz | +16.2 dB |
| GSM | 948 MHz | +19.5 dB |

> This is why GSM needs lower gain than FM even at the same distance — the path loss model accounts for this automatically via `20·log10(freq_hz)`.

### 5.4 Implementation

```python
from math import log10, sqrt

def rssi_to_distance(rssi_dbm, freq_hz, power_w,
                     antenna_gain_dbi, environment) -> float:
    eirp_dbm  = 10 * log10(power_w) + 30 + antenna_gain_dbi
    path_loss = eirp_dbm - rssi_dbm
    path_loss -= environment.extra_loss_db   # obstruction compensation
    d = 10 ** ((path_loss + 147.55 - 20 * log10(freq_hz)) / 20)
    return max(d, 1.0)   # clamp to 1 m minimum
```

---

## 6. Obstruction Compensation (trilateration.py)

### 6.1 Environment Classes

| Class | Description | extra_loss_dB |
|---|---|---|
| OUTDOOR_LOS | Clear line of sight | 0 |
| OUTDOOR_URBAN | Outdoors, buildings present | 5 |
| INDOOR_LIGHT | Inside building, one exterior wall | 15 |
| INDOOR_DEEP | Multiple walls or floors | 27 |

### 6.2 Corrected Distance Formula

Obstruction adds extra loss on top of FSPL. Compensate by subtracting `extra_loss_dB` from the measured path loss before inverting:

```
path_loss_corrected = path_loss_dB − extra_loss_dB
d = 10^((path_loss_corrected + 147.55 − 20·log10(freq_hz)) / 20)
```

Without this correction, an indoor receiver would appear further from all transmitters than it actually is.

### 6.3 Auto-Detection

Run one pass with `OUTDOOR_LOS`. Compute excess loss per source:

```
excess_loss = RSSI_predicted_at_d_freespace − rssi_dbm_measured
```

| Max excess_loss across sources | Detected environment |
|---|---|
| < 3 dB | OUTDOOR_LOS |
| 3–12 dB | OUTDOOR_URBAN |
| 12–22 dB | INDOOR_LIGHT |
| > 22 dB | INDOOR_DEEP |

Re-run with detected class. Two passes total.

### 6.4 RSSI Quality Filter

- `rssi_dbm < entry.min_rssi_dbm` → discard (noise floor)
- `rssi_dbm > −20 dBm` → discard (near-field, model invalid)
- `best_effort = True` → weight reduced by 0.5 in trilateration
- Fewer than 3 valid sources after filtering → return `None`

---

## 7. Trilateration Solver (trilateration.py)

### 7.1 Coordinate System

All solver coordinates are in local East-North metres relative to the centroid of source positions:

```
px = (lon − lon0) × 111320 × cos(radians(lat0))
py = (lat − lat0) × 110540
```

### 7.2 Objective Function

For N sources at known positions `(xi, yi)` with estimated distances `di` and weights `wi`:

```
E(px,py) = Σ wi · (sqrt((px−xi)² + (py−yi)²) − di)²
```

### 7.3 Source Weighting

Weight each source by inverse variance of its distance estimate. Relative uncertainty κ = 0.3 (30% of estimated distance):

```
σi = di · κ
wi = 1 / σi²  =  1 / (di · 0.3)²
```

`best_effort` sources get `wi × 0.5`. This is the only place where source quality affects the solver — a weight multiplier, not an if-else chain.

### 7.4 Solver

```python
from scipy.optimize import minimize
from math import sqrt

def trilaterate_solver(sources) -> tuple[tuple[float,float], float]:
    cx = sum(s["x"] for s in sources) / len(sources)
    cy = sum(s["y"] for s in sources) / len(sources)
    weights = [1. / (s["d_est"] * 0.3)**2 for s in sources]

    def objective(pos):
        px, py = pos
        return sum(
            w * (sqrt((px - s["x"])**2 + (py - s["y"])**2) - s["d_est"])**2
            for s, w in zip(sources, weights)
        )

    result = minimize(
        objective, [cx, cy],
        method="Nelder-Mead",
        options={"xatol": 1.0, "fatol": 1.0, "maxiter": 500}
    )
    return tuple(result.x), result.fun
```

### 7.5 Accuracy Estimation

```
accuracy_m = sqrt(residual / N)
```

Where `N` is number of sources. This is the RMS distance error at the solution. Fed directly into the Kalman filter as `accuracy_m`, which sets measurement noise `R`.

### 7.6 Geometry Check (GDOP)

Detect degenerate geometry where all sources cluster in one direction:

```python
from math import atan2, degrees

def geometry_ok(sources, px, py) -> bool:
    """Reject if all sources lie within a 90-degree arc."""
    angles = sorted(
        degrees(atan2(s["x"] - px, s["y"] - py))
        for s in sources
    )
    gaps = [b - a for a, b in zip(angles, angles[1:])]
    gaps.append(360 - angles[-1] + angles[0])  # wrap-around gap
    return max(gaps) < 270  # False = sources span less than 90 deg
```

If geometry check fails: `accuracy_m *= 3.0`. Do not discard — a poor fix is better than no fix for the Kalman filter.

### 7.7 Environment Accuracy Inflation

| Environment class | accuracy_m multiplier |
|---|---|
| OUTDOOR_LOS | 1.0× |
| OUTDOOR_URBAN | 1.3× |
| INDOOR_LIGHT | 2.0× |
| INDOOR_DEEP | 3.0× |

### 7.8 Public Function

```python
def trilaterate(
    measurements: list[Measurement],
    environment: Environment = Environment.OUTDOOR_LOS,
    origin: tuple[float, float] | None = None
) -> RFMeasurement | None:
    # Stage 1: quality filter (min_rssi, max_rssi, min 3 sources)
    # Stage 2: auto-detect environment (2 passes)
    # Stage 3: rssi_to_distance() with obstruction compensation
    # Stage 4: weighted Nelder-Mead solve
    # Stage 5: geometry check, accuracy inflation
    # Returns RFMeasurement(lat, lon, accuracy_m) or None
```

---

## 8. Kalman Filter (kalman.py)

### 8.1 State Vector

```
x = [px, py, vx, vy]ᵀ   (metres and m/s in local ENU frame)
```

Acceleration is not in the state — it arrives from the IMU each step and is applied via the control input matrix B.

### 8.2 Delta Time (dt)

`dt` is the time elapsed since the last IMU reading in seconds. For a 50 Hz IMU: `dt = 1/50 = 0.02 s`. Pass the actual measured `dt` each call — this handles timing jitter and variable-rate IMUs correctly.

### 8.3 Predict Step

IMU delivers pre-processed `(ax_body, ay_body, heading_deg, dt)`. `FusionEngine` rotates to world frame before calling `predict()`:

```
ax_world = ax_body·sin(ψ) + ay_body·cos(ψ)
ay_world = ax_body·cos(ψ) − ay_body·sin(ψ)

where ψ = radians(heading_deg)
```

State transition:

```
x̂ = F·x̂ + B·[ax_world, ay_world]ᵀ

F = [[1, 0, dt, 0 ],
     [0, 1, 0,  dt],
     [0, 0, 1,  0 ],
     [0, 0, 0,  1 ]]

B = [[dt²/2, 0    ],
     [0,     dt²/2],
     [dt,    0    ],
     [0,     dt   ]]

P = F·P·Fᵀ + Q
```

Process noise Q uses `σ_a = 0.1 m/s²` (tunable constructor argument):

```
Q = σ_a² · [[dt⁴/4, 0,     dt³/2, 0    ],
             [0,     dt⁴/4, 0,     dt³/2],
             [dt³/2, 0,     dt²,   0    ],
             [0,     dt³/2, 0,     dt²  ]]
```

### 8.4 Update Step

Fires when a valid RF fix arrives. `z = [px_rf, py_rf]ᵀ` in local ENU metres. `R = diag(accuracy_m², accuracy_m²)`.

```
H = [[1, 0, 0, 0],
     [0, 1, 0, 0]]

S = H·P·Hᵀ + R
K = P·Hᵀ·S⁻¹
x̂ = x̂ + K·(z − H·x̂)
P = (I − K·H)·P
```

**Outlier gate:** reject fix if Mahalanobis distance `d² = (z−Hx̂)ᵀ·S⁻¹·(z−Hx̂) > 5.991` (χ²₀.₉₅, 2 DOF). Widen to 13.816 during first 10 seconds.

### 8.5 Coordinate Helpers

```python
def latlon_to_enu(lat, lon, lat0, lon0) -> tuple[float, float]:
    px = (lon - lon0) * 111320 * cos(radians(lat0))
    py = (lat - lat0) * 110540
    return px, py

def enu_to_latlon(px, py, lat0, lon0) -> tuple[float, float]:
    lat = lat0 + py / 110540
    lon = lon0 + px / (111320 * cos(radians(lat0)))
    return lat, lon
```

### 8.6 Accuracy Radius Output

```
accuracy_m = sqrt((P[0,0] + P[1,1]) / 2)
```

---

## 9. FusionEngine (fusion.py)

```python
class FusionEngine:
    def __init__(self, sdr: SDRModule, sigma_a=0.1)

    def feed_imu(self, ax_body, ay_body, heading_deg, dt) -> None:
        # Rotates to world frame using heading_deg
        # Calls kf.predict(ax_world, ay_world, dt)

    def step(self) -> PositionEstimate | None:
        # 1. sdr.scan() -> measurements
        # 2. trilaterate(measurements) -> RFMeasurement | None
        # 3. If fix: set origin on first fix, kf.update(px, py, accuracy_m)
        # 4. Return PositionEstimate from current kf state
```

### 9.1 PositioningSystem (public facade)

```python
# sdr_positioning/__init__.py
class PositioningSystem:
    def __init__(self, catalogue_path, driver="sdrplay",
                 serial=None, sigma_a=0.1):
        sdr = SDRModule(catalogue_path, driver, serial)
        self._engine = FusionEngine(sdr, sigma_a)

    def feed_imu(self, ax, ay, heading_deg, dt): ...
    def step(self) -> PositionEstimate | None: ...
    def close(self): ...
```

---

## 10. Implementation Checkpoints

Build in order. Each checkpoint is independently runnable. Do not proceed until the test passes.

---

### Checkpoint 1 — models.py and catalogue loading

Create `models.py` with `Measurement` and `PositionEstimate`. Create `CatalogueLoader`. Verify the existing `stations.json` loads correctly.

```python
from sdr_positioning.sdr_module.catalogue import CatalogueLoader

entries = CatalogueLoader().load("sdr_positioning/stations.json")
fm = [e for e in entries if e.signal_type == "FM"]

assert all(e.freq_hz > 1e6 for e in fm),  "freq must be Hz not MHz"
assert all(e.power_w > 0 for e in entries)
assert all(e.min_rssi_dbm < 0 for e in entries)
assert all(e.max_rssi_dbm == -20. for e in entries)
assert fm[0].antenna_gain_dbi == 0.0  # type default applied

dvbt = [e for e in entries if e.signal_type == "DVB-T"]
if dvbt:
    assert dvbt[0].antenna_gain_dbi == 6.0  # DVB-T type default
```

---

### Checkpoint 2 — Attenuation model: rssi_to_distance()

Implement `rssi_to_distance()` in `trilateration.py`. Test round-trip accuracy and obstruction compensation.

```python
from sdr_positioning.trilateration import rssi_to_distance, Environment
from math import log10

# Synthetic: 50 kW FM at 103.2 MHz, receiver 10 km away, outdoor LOS
power_w, freq_hz, d_true = 50000., 103.2e6, 10000.
eirp_dbm  = 10 * log10(power_w) + 30 + 0.0
fspl      = 20 * log10(d_true) + 20 * log10(freq_hz) - 147.55
rssi_pred = eirp_dbm - fspl

d_est = rssi_to_distance(rssi_pred, freq_hz, power_w, 0.0, Environment.OUTDOOR_LOS)
assert abs(d_est - d_true) < 1., "round-trip must recover true distance"

# Indoor: 15 dB extra loss, INDOOR_LIGHT (extra_loss=15) corrects it
d_indoor = rssi_to_distance(rssi_pred - 15., freq_hz, power_w, 0.0, Environment.INDOOR_LIGHT)
assert abs(d_indoor - d_true) < 100., "indoor correction must approximately recover"

# Frequency effect: higher freq = more FSPL = shorter apparent distance at same RSSI
d_gsm = rssi_to_distance(rssi_pred, 948e6, power_w, 0.0, Environment.OUTDOOR_LOS)
assert d_gsm < d_true, "GSM higher freq must imply shorter apparent distance"
```

---

### Checkpoint 3 — Trilateration solver

Implement the Nelder-Mead solver and geometry check. Test with synthetic data at a known position.

```python
import numpy as np
from sdr_positioning.trilateration import trilaterate_solver, geometry_ok

true_px, true_py = 500., 300.
source_positions = [(0., 0.), (1000., 0.), (1000., 1000.), (0., 1000.)]
np.random.seed(42)
sources = []
for sx, sy in source_positions:
    d = np.sqrt((true_px - sx)**2 + (true_py - sy)**2)
    sources.append({"x": sx, "y": sy, "d_est": d + np.random.normal(0, d * 0.1)})

(px, py), residual = trilaterate_solver(sources)
error = np.sqrt((px - true_px)**2 + (py - true_py)**2)
assert error < 100., f"position error {error:.1f}m must be under 100m"
assert residual >= 0.

# Poor geometry — sources clustered in one direction
bad = [
    {"x": 900., "y": 250., "d_est": 400.},
    {"x": 950., "y": 300., "d_est": 450.},
    {"x": 980., "y": 310., "d_est": 490.},
]
assert not geometry_ok(bad, px, py), "clustered sources must fail geometry check"
```

---

### Checkpoint 4 — AGC and SDRModule with mock hardware

Test `GainController` normalisation and the full `scan()` pipeline.

```python
from sdr_positioning.sdr_module.agc import GainController
from sdr_positioning.sdr_module.catalogue import CatalogueLoader

class MockReceiver:
    TRUE_POWER = -65.   # signal is -65 dBm at antenna
    def __init__(self): self.gain = 0.
    def set_gain(self, g): self.gain = g
    def set_freq(self, f): pass
    def set_sample_rate(self, r): pass
    def read_power_dbm(self, n=4096): return self.TRUE_POWER + self.gain

entry = CatalogueLoader().load("sdr_positioning/stations.json")[0]
agc   = GainController()
m     = agc.measure(entry, MockReceiver())

assert m is not None
assert abs(m.rssi_dbm - (-65.)) < 0.5, "normalised RSSI must equal true power"
assert m.lat == entry.lat and m.lon == entry.lon, "transmitter coords must pass through"

# Saturation — signal too strong
class StrongRx(MockReceiver): TRUE_POWER = -10.
assert agc.measure(entry, StrongRx()) is None

# Noise floor — signal too weak
class WeakRx(MockReceiver): TRUE_POWER = -95.
assert agc.measure(entry, WeakRx()) is None
```

---

### Checkpoint 5 — KalmanFilter

Test predict, update, and outlier rejection.

```python
import numpy as np
from sdr_positioning.kalman import KalmanFilter

kf = KalmanFilter(sigma_a=0.1)
kf.x = np.array([100., 200., 0., 0.])
kf.P = np.diag([100., 100., 25., 25.])

# Static: zero accel, position must not drift
for _ in range(100):
    kf.predict(0., 0., 0.02)
assert abs(kf.x[0] - 100.) < 1e-6
assert kf.P[0, 0] > 100., "uncertainty must grow without updates"

# Update pulls state toward measurement
kf.x = np.zeros(4)
kf.P = np.diag([500., 500., 25., 25.])
ok = kf.update(px_rf=50., py_rf=50., accuracy_m=30.)
assert ok
assert kf.x[0] > 0. and kf.x[1] > 0.
assert kf.P[0, 0] < 500., "uncertainty must shrink after update"

# Outlier rejected — tight P, wildly inconsistent fix
kf.P = np.diag([10., 10., 1., 1.])
assert not kf.update(9999., 9999., 30.), "outlier must be rejected"
```

---

### Checkpoint 6 — Full integration smoke test

Wire all components through `PositioningSystem`. Uses mock hardware throughout.

```python
from unittest.mock import patch, MagicMock
from sdr_positioning import PositioningSystem

with patch("sdr_positioning.sdr_module.receiver.SoapySDR") as mock_soapy:
    mock_soapy.Device.return_value = MagicMock()

    ps = PositioningSystem("sdr_positioning/stations.json")
    ps._engine.sdr.receiver.read_power_dbm = lambda n=4096: -60.
    ps._engine.sdr.receiver.set_gain = lambda g: None
    ps._engine.sdr.receiver.set_freq = lambda f: None
    ps._engine.sdr.receiver.set_sample_rate = lambda r: None

    # Before first fix — no estimate
    assert ps.step() is None

    # IMU feed must not crash
    ps.feed_imu(ax=0.1, ay=0., heading_deg=45., dt=0.02)
    result = ps.step()
    if result is not None:
        assert result.accuracy_m > 0.
        assert -90 < result.lat < 90
        assert -180 < result.lon < 180

    ps.close()
    print("Integration smoke test: OK")
```

---

## 11. Extension Points

| Extension | Where and how |
|---|---|
| New signal type | Add to `GAIN_STRATEGIES` in `agc.py` + `TYPE_DEFAULTS` in `catalogue.py`. Zero other changes. |
| New hardware | Implement `SDRReceiver` interface. Pass `driver=` to `SDRModule`. |
| Phone LTE cells (v2) | Add `PhoneCellSource` to `sdr_module/` implementing same `Measurement` output. `FusionEngine` polls it transparently. |
| VOR bearing (EKF) | Add `kf.update_bearing()` to `kalman.py`. `trilateration.py` unchanged. |
| GPS cross-check | Add `GPSValidator` to `fusion.py`. Never integrates GPS — compares against `kf.x` and emits spoofing flag. |
| REST API output | Wrap `PositioningSystem` in FastAPI. `PositionEstimate` is a dataclass — `json.dumps(asdict(estimate))`. |

---

## 12. Design Rules

- SoapySDR imported in exactly one file: `receiver.py`
- `true_power = measured - gain` appears exactly once: `GainController.measure()`
- FSPL formula appears exactly once: `rssi_to_distance()` in `trilateration.py`
- `CatalogueEntry` is frozen — immutable after load
- `Measurement.rssi_dbm` is always normalised before leaving `sdr_module/`
- Adding a signal type requires editing two dicts, zero if-else chains
- `scan()` never raises — returns empty list if no signals found
- `trilaterate()` never raises — returns `None` if insufficient sources
- `step()` never raises — returns `None` if no fix available yet

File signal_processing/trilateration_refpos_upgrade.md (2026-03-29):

# SDR Positioning System
## Trilateration Upgrade — Reference Position Integration

Upgrade instructions for trilateration.py | 2026-03-28

---

## 1. What This Upgrade Does

The existing `trilaterate()` function works without any prior position knowledge. This upgrade adds an optional `ref_pos` argument — a tuple of `(px, py)` in local ENU metres already computed by the operations loop — that improves accuracy in four ways when provided.

| Improvement | What it does |
|---|---|
| Source pre-selection | Skip sources too far to be useful at ref_pos. Shorter scan, less noise. |
| RTK n calibration | Solve for the real path loss exponent n using geometric distances from ref_pos. Replaces the fixed environment default. |
| Per-source outlier flag | Sources whose implied distance badly disagrees with the geometric distance from ref_pos get half weight. Not discarded. |
| Solver seed | Nelder-Mead starts at ref_pos instead of the source centroid. Fewer iterations, less risk of local minima. |

> When `ref_pos` is `None` all four improvements are skipped. Behaviour is identical to the existing implementation. No existing tests should break.

---

## 2. What Is Already Available

The following already exist in `sdr_positioning` and must be used directly. Do not reimplement them in `trilateration.py`.

| Already exists in sdr_positioning | Used here for |
|---|---|
| `latlon_to_enu(lat, lon, lat0, lon0) -> (px, py)` | Converting source lat/lon to ENU for geometric distance computation |
| `enu_to_latlon(px, py, lat0, lon0) -> (lat, lon)` | Converting solver output back to lat/lon for RFMeasurement |
| `Measurement` dataclass | Input — already carries freq_hz, power_w, antenna_gain_dbi, lat, lon, rssi_dbm |
| `RFMeasurement` dataclass | Output — lat, lon, accuracy_m, n_sources |
| `Environment` enum + `extra_loss_db` | Already used in `rssi_to_distance()` |

> **TODO for the implementer:** `trilaterate()` already uses `latlon_to_enu()` internally to convert source positions into ENU for the solver. Verify this is already in place before adding the `ref_pos` steps. If it is not, add it first as a prerequisite — convert each source lat/lon to `(x, y)` ENU using the shared origin, store as `source.x` and `source.y`. This is what the `ref_pos` comparisons below rely on.

---

## 3. Signature Change

One new optional argument. Everything else stays the same.

```python
# Before
def trilaterate(measurements, environment, origin) -> RFMeasurement | None

# After
def trilaterate(measurements, environment, origin,
                ref_pos=None) -> RFMeasurement | None
#
# ref_pos: tuple[float, float] | None
# ref_pos is (px, py) in local ENU metres
# — the same frame as kf.x[0], kf.x[1] in the operations loop
```

`FusionEngine` passes `ref_pos` from the Kalman state on every triggered scan after initialisation:

```python
ref_pos = (self.kf.x[0], self.kf.x[1])
result  = trilaterate(measurements, environment, self.origin, ref_pos=ref_pos)
```

On the very first scan (before initialisation), `FusionEngine` passes `ref_pos=None`.

---

## 4. Accuracy Stability Across Cycles

A key concern: the reference position used for calibration comes from the previous cycle's fix. If a bad fix calibrates a bad `n`, and that bad `n` produces another bad fix, the system can drift. Two rules prevent this.

### 4.1 Clamp n to physical bounds

The calibrated `n` must always be clamped, regardless of what the data suggests:

```python
n_calibrated = max(1.5, min(5.0, n_raw))
```

`n < 1.5` is physically impossible (better than free space). `n > 5.0` occurs only in extreme multipath and likely indicates a bad measurement. Clamping prevents a single bad RSSI from driving the model into nonsense.

### 4.2 Only calibrate when ref_pos is credible

The Kalman filter provides the accuracy of the reference position via the Kalman covariance. `FusionEngine` should only pass `ref_pos` when the current Kalman accuracy is below a useful threshold:

```python
# In FusionEngine._rf_scan():
kf_accuracy = sqrt((self.kf.P[0,0] + self.kf.P[1,1]) / 2)
ref_pos = (self.kf.x[0], self.kf.x[1]) if kf_accuracy < 300. else None
```

300 m is a generous threshold. If Kalman accuracy is worse than 300 m, the reference position is too uncertain to calibrate against — fall back to `ref_pos=None` and let the solver run without guidance. After a good RF fix the accuracy will be well within this limit for the next cycle.

> The 300 m threshold means: after a long IMU-only dropout where position uncertainty has grown large, the next RF scan runs without `ref_pos` assistance. This is correct — a degraded reference would corrupt the calibration. Once the scan produces a new fix, accuracy drops back down and subsequent cycles use `ref_pos` normally.

### 4.3 Accuracy does not drift between cycles

With these two rules in place, each RF scan cycle is independent of the previous calibration. The `n` used for one scan does not persist to the next — it is re-solved fresh from the current RSSI measurements and the current `ref_pos`. A bad `n` in cycle K cannot corrupt cycle K+1 because cycle K+1 re-derives `n` from scratch.

The only persistent state between cycles is the Kalman filter state (position and velocity), which is self-correcting by design — the Kalman update always pulls the state toward the measurement, bounded by the innovation gate.

---

## 5. Implementation — Four Steps

Add these four blocks inside `trilaterate()`, in order, after the quality filter and before the solver call. Each block is gated on `ref_pos is not None` and is fully self-contained.

### Step A — Source Pre-selection

Drop sources whose expected signal at `ref_pos` is clearly below the noise floor. Never drop below 3 sources total.

```python
if ref_pos is not None:
    kept = []
    for s in located:
        # s.x, s.y already in ENU — from latlon_to_enu() earlier in function
        d_geo = max(sqrt((ref_pos[0]-s.x)**2 + (ref_pos[1]-s.y)**2), 1.)
        fspl  = 20*log10(d_geo) + 20*log10(s.freq_hz) - 147.55
        rssi_expected = s.eirp_dbm - fspl
        if rssi_expected >= s.min_rssi_dbm - 5.:
            kept.append(s)
    if len(kept) >= 3:
        located = kept
    # else: keep original list — never drop below 3 sources
```

### Step B — RTK Path Loss Calibration

Solve for `n` per source using the geometric distance from `ref_pos`. Average. Clamp.

```python
n_calibrated = 2.0  # default if ref_pos absent or calibration fails
if ref_pos is not None:
    ns = []
    for s in located:
        d_geo = max(sqrt((ref_pos[0]-s.x)**2 + (ref_pos[1]-s.y)**2), 1.)
        path_loss = s.eirp_dbm - s.rssi_dbm - environment.extra_loss_db
        fspl_1m   = 20*log10(s.freq_hz) - 147.55  # FSPL at d=1m
        if path_loss > fspl_1m and d_geo > 10.:
            n = (path_loss - fspl_1m) / (10 * log10(d_geo))
            ns.append(max(1.5, min(5.0, n)))  # clamp immediately
    if len(ns) >= 2:  # require at least 2 sources to trust calibration
        n_calibrated = sum(ns) / len(ns)
```

Pass `n_calibrated` into `rssi_to_distance()` for all sources in this scan cycle.

### Step C — Per-source Outlier Flag

After calibration, reduce weight of sources that disagree badly with the reference geometry. Do not discard.

```python
if ref_pos is not None:
    for s in located:
        d_geo  = max(sqrt((ref_pos[0]-s.x)**2 + (ref_pos[1]-s.y)**2), 1.)
        delta  = abs(s.d_est - d_geo)
        if delta > 0.3 * d_geo:
            s.weight *= 0.5
```

> 30% threshold is deliberately loose. The solver handles residual noise. This only catches gross outliers — multipath, obstructions, a far-off source whose AGC measurement was unreliable.

### Step D — Solver Seed

Seed Nelder-Mead at `ref_pos` when available, source centroid otherwise.

```python
x0 = list(ref_pos) if ref_pos is not None else \
     [mean(s.x for s in located), mean(s.y for s in located)]

result = minimize(objective, x0, method="Nelder-Mead",
                  args=(located,),
                  options={"xatol": 1.0, "fatol": 1.0, "maxiter": 500})
```

---

## 6. Checkpoints

---

### Checkpoint 1 — latlon_to_enu already used inside trilaterate()

Prerequisite check — verify source positions are already being converted to ENU before adding `ref_pos` steps. If not, this must be fixed first.

```python
# Inspect trilaterate() source — look for latlon_to_enu() calls
# Each located source must have .x and .y attributes in ENU metres
# before the solver loop runs.

# Quick verification:
import inspect, sdr_positioning.trilateration as t
src = inspect.getsource(t.trilaterate)
assert "latlon_to_enu" in src, "TODO: add ENU conversion before proceeding"
```

---

### Checkpoint 2 — ref_pos=None gives same result as before

```python
fix_none = trilaterate(measurements, env, origin, ref_pos=None)
fix_base = trilaterate(measurements, env, origin)  # old signature

# Both must return a fix or both None
assert (fix_none is None) == (fix_base is None)
if fix_none:
    assert abs(fix_none.lat - fix_base.lat) < 1e-6
    assert abs(fix_none.lon - fix_base.lon) < 1e-6
```

---

### Checkpoint 3 — RTK calibration improves accuracy vs wrong environment class

True environment is n=3.5 (indoor). Environment class is `OUTDOOR_LOS` (n=2.0). With a good `ref_pos`, calibration should recover `n` closer to 3.5 and produce a more accurate fix.

```python
true_px, true_py = 300., 400.
sources = make_sources_with_n(true_px, true_py, n=3.5)

fix_no_ref = trilaterate(sources, OUTDOOR_LOS, origin, ref_pos=None)
fix_ref    = trilaterate(sources, OUTDOOR_LOS, origin,
                         ref_pos=(true_px, true_py))

err_no_ref = dist_m(fix_no_ref, true_px, true_py)
err_ref    = dist_m(fix_ref,    true_px, true_py)
assert err_ref < err_no_ref, "ref_pos must improve indoor accuracy"
```

---

### Checkpoint 4 — Bad ref_pos (accuracy > 300 m) falls back to ref_pos=None

Tests the `FusionEngine` threshold logic — not `trilaterate()` itself.

```python
import numpy as np
engine = FusionEngine(sdr, sigma_a=0.1)
engine._initialised = True
engine.kf.P = np.diag([310.**2, 310.**2, 25., 25.])  # >300m accuracy
engine.kf.x = np.array([100., 200., 0., 0.])

# Patch trilaterate to capture what ref_pos was passed
captured = {}
def mock_trilat(meas, env, origin, ref_pos=None):
    captured["ref_pos"] = ref_pos
    return None

with patch("fusion.trilaterate", mock_trilat):
    engine._rf_scan(ref_pos=(100., 200.))
assert captured["ref_pos"] is None, "degraded Kalman must pass ref_pos=None"
```

---

### Checkpoint 5 — n is clamped — bad RSSI cannot produce extreme n

```python
# Synthesise a source with absurd RSSI (near-field bleed)
# that would compute n < 1.5 or n > 5.0 without clamping
sources_extreme = make_sources_extreme_rssi()
fix = trilaterate(sources_extreme, OUTDOOR_LOS, origin,
                  ref_pos=(true_px, true_py))
# Should not raise, should not return None
assert fix is not None, "clamped n must still produce a fix"
assert fix.accuracy_m < 5000., "accuracy must be finite and sane"
```

---

## 7. What Not to Change

- The FSPL formula — `rssi_to_distance()` is untouched
- The environment class `extra_loss_db` — still applied before n calibration
- The geometry check (GDOP) — runs after the solver regardless of `ref_pos`
- The `accuracy_m` formula — `sqrt(residual / N)` unchanged
- The `RFMeasurement` return type — unchanged
- `latlon_to_enu` / `enu_to_latlon` — already in `sdr_positioning`, import from there

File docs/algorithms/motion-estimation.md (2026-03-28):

# Motion Estimation

This document describes the motion-estimation code that exists in the repo
today. It is intentionally precise about what is implemented and what is not.

## Scope

The current motion stack uses:

- the MPU-6050 accelerometer
- the QMC5883L magnetometer
- optional accelerometer-derived tilt compensation
- a simple dead-reckoning loop with zero-velocity updates

The current motion stack does not use:

- the MPU-6050 gyroscope
- complementary filtering
- Kalman filtering
- Madgwick or Mahony fusion
- quaternion attitude estimation

If the documentation says "accelerometer + gyroscope" at this stage, that would
be inaccurate.

## Inputs And Units

The HAL protocols define the units used by the motion code:

- `AccelerationReader.read_accel_g()`
  - returns `(ax, ay, az)` in `g`
  - `1.0 g` is approximately `9.81 m/s^2`
- `TiltReader.read_pitch_roll()`
  - returns `(pitch, roll)` in degrees
- `RotationReader.read_azimuth()`
  - returns heading in degrees clockwise from north

The dead-reckoning output is:

- `(x, y)` in meters
- relative to the start point
- in a local 2D frame, not in latitude/longitude

## 1. Accelerometer Processing With The MPU-6050

The MPU-6050 code in `firmware/hal/mpu6050.py` reads six accelerometer bytes
from the standard register block beginning at `0x3B`.

### Raw Conversion

Each axis is reconstructed as a signed 16-bit integer:

```text
raw = (msb << 8) | lsb
if raw >= 0x8000:
    raw -= 0x10000
```

The code assumes the default +/-2 g range, so the scale factor is:

```text
ACCEL_SCALE = 16384 LSB / g
```

Converted values are:

```text
g_x = raw_x / 16384
g_y = raw_y / 16384
g_z = raw_z / 16384
```

This is a fixed-range assumption. If the sensor range were changed at the
register level, the math in the current implementation would become incorrect
unless the scale factor were updated too.

### Tilt Estimation

The current tilt estimator derives pitch and roll from the gravity vector:

```text
pitch = atan2(-g_x, sqrt(g_y^2 + g_z^2))
roll  = atan2(g_y, g_z)
```

The implementation returns the angles in degrees.

Interpretation:

- pitch is rotation around the device Y axis
- roll is rotation around the device X axis

Important caveat:

- this is accelerometer-derived tilt only
- fast motion corrupts the gravity estimate
- no gyroscope smoothing or dynamic fusion is applied

## 2. Magnetometer Heading With Optional Tilt Compensation

The QMC5883L code in `firmware/hal/qmc5883l.py` reads the magnetic field vector
`(mx, my, mz)` over I2C.

### Heading Without Tilt Compensation

If no `TiltReader` is supplied, the code computes:

```text
heading = atan2(my, mx)
```

The result is converted to degrees and normalized to the range `[0, 360)`.

### Heading With Tilt Compensation

If a `TiltReader` is supplied, the raw magnetic vector is projected onto the
horizontal plane before the azimuth is computed.

Let:

- `p = pitch` in radians
- `r = roll` in radians

Then the code computes:

```text
x_h = mx cos(p) + my sin(r) sin(p) + mz cos(r) sin(p)
y_h = my cos(r) - mz sin(r)
heading = atan2(y_h, x_h)
```

The heading is then normalized to `[0, 360)`.

### What That Heading Means

The current heading is:

- magnetic heading
- not corrected for magnetic declination
- sensitive to hard-iron and soft-iron distortion
- dependent on the physical mounting of the sensor

So the correct interpretation is:

"clockwise angle from magnetic north, according to the current uncalibrated
sensor frame."

## 3. Dead-Reckoning Loop

The dead-reckoning code lives in `firmware/hal/dead_reckoning.py`.

Its update loop is:

1. read acceleration `(ax, ay, az)` in `g`
2. read heading `h` in degrees
3. detect stillness using a zero-velocity rule
4. if moving, rotate horizontal acceleration into a world frame
5. integrate acceleration into velocity
6. integrate velocity into position

### Stillness Detection (ZUPT)

The code computes acceleration magnitude:

```text
|a| = sqrt(ax^2 + ay^2 + az^2)
```

It then checks:

```text
abs(|a| - 1.0) < 0.06
```

If that condition is true, the tracker assumes the device is stationary and
forces:

```text
vx = 0
vy = 0
```

This is a simple zero-velocity update, or ZUPT.

### Horizontal Acceleration

If the stillness test fails, the current implementation does:

```text
lin_x = ax * 9.81
lin_y = ay * 9.81
```

This is an important point of truthfulness:

- the code comment says it "removes gravity"
- but it does not subtract a fully rotated gravity vector
- it simply treats the accelerometer X and Y channels as horizontal linear
  acceleration after the stillness check

That means the approximation is only reasonable when the device stays roughly
level.

### Rotation Into The World Frame

With heading `h` in radians:

```text
world_ax = lin_x cos(h) - lin_y sin(h)
world_ay = lin_x sin(h) + lin_y cos(h)
```

This converts the body-frame horizontal acceleration into the local world frame
used by the tracker.

### Integration

The tracker uses first-order Euler integration with wall-clock `dt`:

```text
vx = vx + world_ax * dt
vy = vy + world_ay * dt

x = x + vx * dt
y = y + vy * dt
```

This is simple and easy to reason about, but it is also drift-prone.

## 4. Measurement Trigger In The Walking POC

The walking POC in `firmware/scripts/sweep_poc.py` uses the dead-reckoned
position to decide when to collect a new cell measurement.

If the operator has moved at least:

```text
HAL_TRIGGER_DISTANCE
```

meters from the previous measurement, the code triggers `cell_reader.read_cells()`.

The default threshold is `2.0` meters.

This means the motion estimator is not just visualization support. It actively
controls the spatial sampling of the POC measurements.

## 5. Coordinate Frames

One thing the repo does not yet define rigorously is the full physical
coordinate-frame convention.

What is clear:

- the tracker maintains a 2D local `(x, y)` frame
- heading is used to rotate horizontal acceleration into that frame
- the frame origin is the start point

What is not yet formalized:

- which physical device axis is "forward"
- which world axis should be interpreted as north or east
- how mounting offsets should be calibrated

The current implementation therefore works best as:

- a relative motion estimate for a controlled prototype
- a trigger source for collecting spaced measurements

It should not be described as a fully specified inertial navigation frame.

## 6. Limitations

The main limitations of the current motion estimator are:

- no gyroscope integration
- no fusion algorithm
- no explicit gravity-vector subtraction in an arbitrary orientation
- no accelerometer bias calibration
- no magnetometer hard-iron or soft-iron calibration
- no magnetic declination correction
- simple ZUPT based only on acceleration magnitude
- Euler integration with variable wall-clock `dt`

These are not documentation problems; they are real algorithmic limitations in
the present code, and the documentation should say so plainly.

## 7. Upgrade Path

A future IMU-navigation version of the project would likely introduce these
steps:

1. read and bias-correct gyroscope data from the MPU-6050
2. estimate attitude with a complementary filter, Mahony, Madgwick, or EKF
3. rotate body-frame acceleration into the world frame with that attitude
4. subtract gravity in the world frame, not by the current "roughly level"
   shortcut
5. use a stronger stillness detector that also considers gyro motion and window
   statistics
6. calibrate magnetometer offsets and optionally apply declination

Until that work lands, the honest description is:

"prototype dead reckoning from accelerometer data and magnetic heading."

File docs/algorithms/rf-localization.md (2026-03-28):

# RF Localization Pipeline

This document explains the current RF path in the repository and stays aligned
with the algorithms that are actually implemented today.

## Scope

The current codebase implements a GSM-oriented pipeline built around:

- `grgsm_scanner`
- a `CellKey` made from `(mcc, mnc, lac, ci)`
- local OpenCellID CSV lookup
- a heuristic final position estimate in the main app

This is not yet an LTE protocol document. The end of this file explains how the
same documentation structure can be extended once LTE and richer SDR work land.

## 1. Observations And Data Structures

The RF path uses two central data structures:

- `CellKey`
  - `mcc`
  - `mnc`
  - `lac`
  - `ci`
- `SweepSample`
  - time `t`
  - azimuth `azimuth_deg`
  - map of `CellKey -> RSSI`

The RF pipeline is therefore built around the question:

"At this heading and this time, which cells were visible and how strong were
they?"

## 2. Scanner Parsing

`firmware/hal/grgsm_scanner.py` expects stdout lines like:

```text
ARFCN: 512, Freq: 1930.2M, CID: 3492, LAC: 32451, MCC: 310, MNC: 26, Pwr: -57
```

The parser extracts:

- `CID`
- `LAC`
- `MCC`
- `MNC`
- `Pwr`

and converts them into:

```text
CellKey(mcc, mnc, lac, ci), rssi_dbm
```

This means the current code is only as rich as the fields exposed by that text
format. The parser does not currently retain additional scanner metadata such
as bandwidth, channel confidence, timing information, or modulation details.

## 3. Sweep Construction

The sweep source `GrgsmScannerSource` performs repeated scan iterations.

For each iteration it:

1. reads the current azimuth from a `RotationReader`
2. runs the scanner command
3. parses the scanner output
4. emits one `SweepSample`

So the mathematical object produced by the live scan path is:

```text
sample_i = (t_i, heading_i, {cell_j -> rssi_ij})
```

The scan count is controlled by `HAL_GRGSM_N_SCANS`, defaulting to `36`.

## 4. Tower Resolution Through OpenCellID

The module `firmware/opencellid.py` resolves a `CellKey` to coordinates by
opening:

```text
firmware/data/<mcc>.csv
```

and finding a row that matches:

- `mcc`
- `net` as MNC
- `area` as LAC
- `cell` as CI

If a matching row is found, the code returns:

- `lat`
- `lon`

If the CSV for that MCC does not exist, the current implementation exits the
program with a fatal error. In other words, tower lookup is not an optional
detail in the main e-paper flow; it is a required dependency.

## 5. Scan Aggregation In The Main App

The scan worker in `firmware/ui/app.py` consumes `SweepSample` values and keeps
the best RSSI seen for each discovered tower.

For each observed cell:

- if the tower is new, it is labeled `T1`, `T2`, `T3`, and so on
- if the tower was already seen, its stored RSSI is replaced only when a
  stronger observation arrives
- tower coordinates are looked up through OpenCellID

The resulting tower state shown in the UI is therefore:

```text
DiscoveredTower = (
    key,
    lat,
    lon,
    best_rssi,
    label
)
```

This aggregation step is a "best observation per tower" heuristic, not a full
probabilistic observation history.

## 6. Current Position Estimate In The Main App

When the scan finishes, `firmware/ui/app.py` computes a single latitude and
longitude estimate from the resolved towers.

Only towers with known coordinates are used.

The code computes a weight for each tower:

```text
w_i = 10^(rssi_i / -20)
```

Then:

```text
lat_est = sum(w_i * lat_i) / sum(w_i)
lon_est = sum(w_i * lon_i) / sum(w_i)
```

This is an RSSI-weighted centroid heuristic.

Two important truthfulness notes belong in the documentation:

1. This is not trilateration or multilateration.
2. Because RSSI values are negative in dBm, the implemented formula
   `10^(rssi / -20)` increases as RSSI becomes weaker. That means the current
   code gives more weight to weaker signals, even though the nearby code
   comment says the opposite. The documentation should describe the formula as
   implemented and flag this as a heuristic that likely needs revision.

So the most accurate wording today is:

"The main app currently uses a centroid-style RF position heuristic, not a
geometrically derived trilateration solver."

## 7. What The Mock Backends Simulate

The development backends are mathematically useful because they turn the system
into something deterministic and testable.

### Mock Sweep Source

`firmware/hal/mock.py` creates directional tower observations across a synthetic
360 degree sweep.

For each tower, RSSI is:

```text
rssi(az) = -50 - 40 (1 - cos(delta))
```

where `delta` is the wrapped angular difference between the current azimuth and
the tower's peak azimuth.

This gives each synthetic tower a smooth directional lobe.

### Mock Cell Reader

`firmware/hal/mock_cells.py` creates a position-dependent RSSI field over a
local `(x, y)` map.

For each tower at distance `d` meters:

```text
rssi(d) = -30 - 20 log10(max(d, 1))
```

This is a simple log-distance path-loss model. It is intentionally lightweight
and should be documented as a test heuristic, not as a validated propagation
model.

## 8. What The Current RF Stack Does Not Do

The current implementation does not do any of the following:

- true trilateration
- multilateration using time or phase
- confidence estimation
- probabilistic filtering over multiple scans
- sector modeling
- calibration against measured propagation environments
- LTE-specific identity parsing
- fusion between RF observations and the dead-reckoning track

These absences matter, because they determine how ambitious the docs should be.
The project is already technically interesting without pretending it does more
than the current code supports.

## 9. Future LTE And SDR Documentation Structure

When LTE work lands, the cleanest extension is to keep this same layered
structure and add richer details in the protocol-specific sections.

### Section That Can Stay The Same

- observation model
- capture and parsing layer
- tower-resolution layer
- positioning layer
- limitations and assumptions

### Section That Will Likely Change For LTE

- identity model
  - current GSM-oriented key: `(mcc, mnc, lac, ci)`
  - future LTE observations may need TAC, ECI, PCI, EARFCN, or related fields
- signal metrics
  - current code is effectively RSSI-centric
  - LTE may use RSRP, RSRQ, SINR, or other measurements
- scan tooling
  - current: `grgsm_scanner`
  - future: LTE-capable demodulation or a lower-level SDR pipeline

### Recommended Documentation Strategy For Future Commits

When LTE support is added, extend this file with new sections rather than
replacing the GSM story:

- `GSM Path`
- `LTE Path`
- `Shared Geolocation Model`
- `Positioning Heuristics And Filters`

That keeps the documentation historically accurate and makes algorithm changes
easier to compare over time.

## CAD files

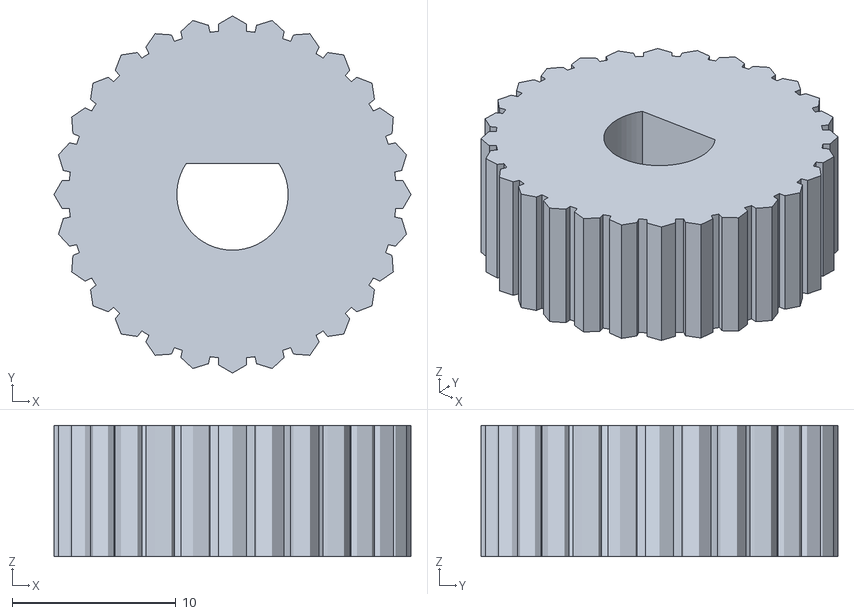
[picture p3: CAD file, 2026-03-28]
assets/3D/SCROLL.stl
21.8 x 21.8 x 8.00

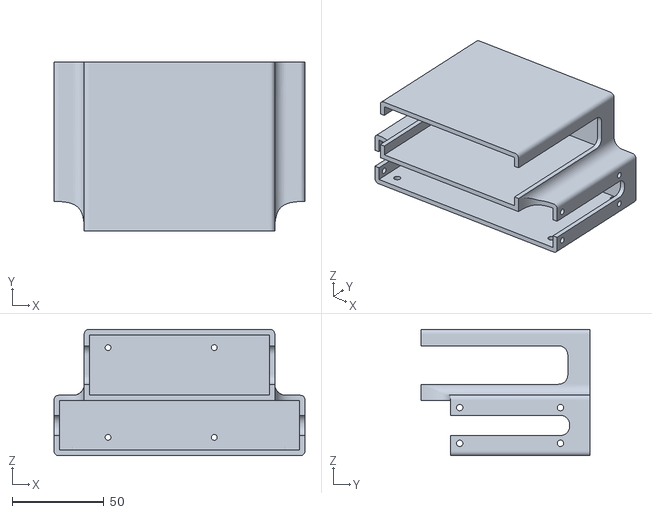
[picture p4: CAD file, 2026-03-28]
assets/3D/TOOESHOLSTER.stl
137.0 x 92.0 x 69.0

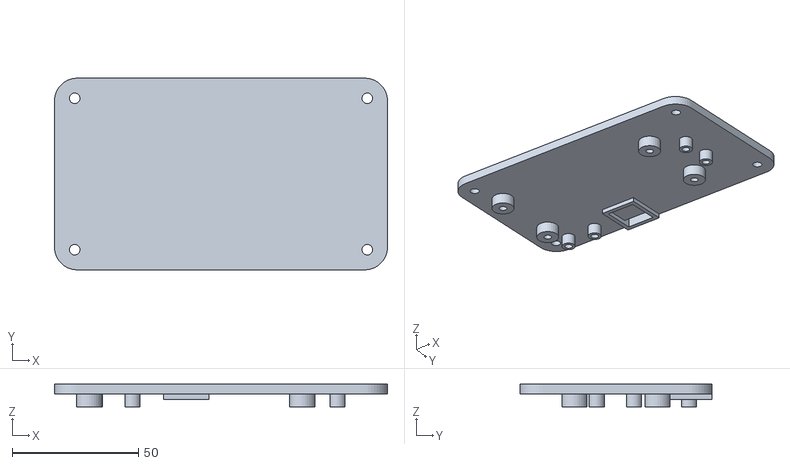
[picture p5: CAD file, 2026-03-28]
assets/3D/COMPONENTSPLATE.stl
132.0 x 76.0 x 9.00

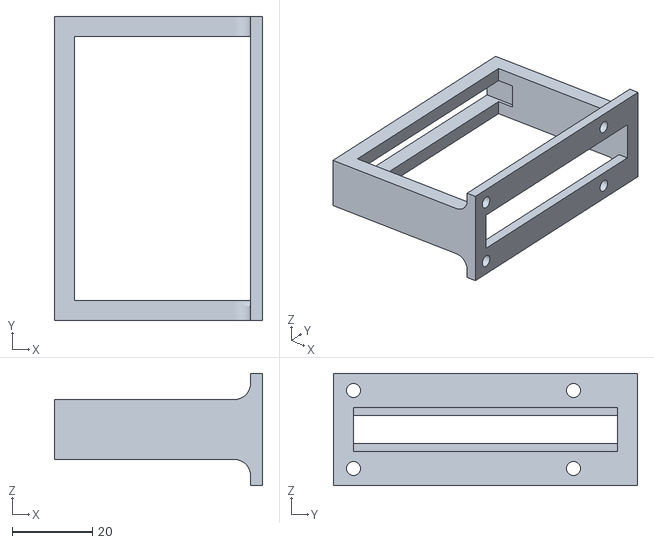
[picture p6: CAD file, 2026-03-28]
assets/3D/TOOESHANDLE.stl
52.0 x 76.0 x 28.0

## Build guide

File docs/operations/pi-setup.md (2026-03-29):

# Raspberry Pi Setup And Operations

This guide covers the operational setup needed to run the current repo on a
Raspberry Pi. It stays close to what the repo already automates and calls out
the steps that are still manual.

## What This Setup Covers

- syncing the repo to the Pi (rsync + git pseudoclone)
- populating the Waveshare display submodule
- enabling I2C and verifying sensors
- installing Python runtime dependencies
- creating the required `.env.local` configuration
- syncing local tower data
- running the main app or the walking POC

## What This Setup Does Not Fully Automate Yet

- installing `grgsm_scanner`
- installing GNU Radio or SoapySDR driver chains
- provisioning SDR hardware drivers
- downloading OpenCellID CSV files
- downloading offline map tiles

Those are all real operational dependencies even though they sit outside the
Python code.

## 1. Prepare The Checkout

On a fresh checkout, populate the Waveshare submodule:

```bash
git submodule update --init --recursive
```

Without this, the main e-paper application cannot import the display driver.

## 2. Sync Or Clone The Repo To The Pi

The repo contains a helper script that rsyncs the code, initialises a git repo
on the Pi, sets the GitHub remote, and configures I2C in one shot:

```bash
PI_PASS=<password> bash scripts/setup_pi.sh [user@host]
```

What the script does:

1. Rsyncs the full repo to `~/Tooes/` on the Pi (faster than cloning over a
   hotspot)
2. Rsyncs `firmware/data/` separately (OpenCellID CSVs are excluded from git)
3. Initialises a git repo on the Pi, adds the GitHub remote, and checks out
   `main` — so `git pull` works for all future updates
4. Enables I2C via `raspi-config`
5. Installs `i2c-tools` and `smbus2`
6. Runs `i2cdetect -y 1` to verify the magnetometer is wired correctly

Default target: `team@tooes.local` (fallback: `team@10.15.86.130`)

Requires `sshpass` on the laptop:

```bash
apt install sshpass   # Debian/Ubuntu
```

After the first sync, pull updates from GitHub directly on the Pi:

```bash
ssh team@tooes.local "cd ~/Tooes && git pull"
```

## 3. Install Python Dependencies

The Pi runtime dependencies live in `firmware/requirements.txt`. The setup
script currently installs only `smbus2`, so install the rest manually:

```bash
ssh team@tooes.local
cd ~/Tooes
pip3 install --break-system-packages -r firmware/requirements.txt
```

Notes:

- `RPi.GPIO` and `spidev` are Pi-specific; install them on the Pi, not on a
  laptop development machine
- The `smbus2` package may already be installed by the setup script

## 4. Enable And Verify I2C

The setup script runs `raspi-config` automatically. If you need to do it
manually:

```bash
sudo raspi-config nonint do_i2c 0
```

Then verify the bus:

```bash
i2cdetect -y 1
```

Expected sensor addresses:

- `0x0d` — QMC5883L magnetometer (GY-271 board)
- `0x68` — MPU-6050 accelerometer / gyroscope

If those addresses do not appear, debug wiring before debugging the software.
See the wiring tables in `docs/hardware.md`.

## 5. Create The `.env.local` Configuration File

The navigation runtime requires a starting location. Create `.env.local` at
the repo root on the Pi:

```bash
ssh team@tooes.local
cd ~/Tooes
cat > .env.local <<'EOF'
INITIAL_L=42.012280,23.095261
EOF
```

Replace the coordinates with your actual starting location. `INITIAL_L` is the
absolute position the firmware uses as its initial anchor. The navigation
engine then tracks short-range IMU movement locally and blends in SDR fixes as
corrections over time.

Additional optional settings you can add to `.env.local`:

```bash
# SDR hardware
SDR_DRIVER=sdrplay          # SoapySDR driver name (default: sdrplay)
SDR_SERIAL=                 # Serial number if you have multiple devices

# Tuning
NAV_TRIGGER_DISTANCE_M=25.0 # SDR fix interval in metres (default: 25.0)
SDR_CONFIDENCE_RADIUS_M=500.0 # Radius within which an SDR fix is trusted (m)

# Path logging (enabled by default)
NAV_PATH_LOG_ENABLED=true   # Set to false to disable
# NAV_PATH_LOG_PATH=firmware/logs/my_trace.jsonl  # Custom log path
```

All settings can also be passed as shell environment variables; shell exports
take precedence over `.env.local`.

## 6. Provide OpenCellID Data

The tower lookup path requires local CSV files in `firmware/data/`.

The lookup code expects one file per MCC, for example:

- `firmware/data/284.csv` (Bulgaria, MCC 284)

If the file is missing, the live tower-resolution path will fail at runtime
even though the code deployed successfully.

The setup script syncs `firmware/data/` if the directory exists locally.
To re-sync it manually:

```bash
# From your laptop, at the repo root:
rsync -avz --progress firmware/data/ team@tooes.local:~/Tooes/firmware/data/
```

## 7. Download Offline Tiles If You Need The Map View

The map view reads from `firmware/offline_tiles/`. To populate it:

```bash
python3 firmware/scripts/install_tiles.py
```

Only use this with a tile provider whose terms allow offline or bulk download.
If tiles are missing, the app falls back to placeholder tiles rather than
crashing.

## 8. Run The Main E-Paper Application

### Prerequisites

- Waveshare submodule populated (`git submodule update --init --recursive`)
- I2C enabled and sensors visible on the bus
- `grgsm_scanner` installed and tested in a shell (see step 9)
- `firmware/data/<mcc>.csv` present on the device
- `.env.local` created with `INITIAL_L`

### Launch command

```bash
HAL_BACKEND=grgsm \
HAL_ROTATION=qmc5883l \
HAL_ACCEL=mpu6050 \
HAL_GRGSM_SCANNER_CMD="grgsm_scanner -b GSM900 -a 'driver=sdrplay'" \
python3 -m firmware.run
```

The app reads `.env.local` automatically on startup. While running, it:

- displays a boot splash then a tutorial screen
- launches a background navigation worker that fuses IMU position with
  periodic SDR fixes
- renders a map with your trace path, heading, and discovered towers
- writes the fused trace to `firmware/logs/navigation_trace_*.jsonl` (disable
  with `NAV_PATH_LOG_ENABLED=false`)

Use the rotary encoder to zoom the map. The button triggers a manual scan.

## 9. Radio Prerequisites

The repo assumes the scanner command itself is already working.

That usually means:

- SDR device connected and recognised by the OS
- appropriate SoapySDR driver installed
- `grgsm_scanner` invocations tested directly in a shell before passing them
  to `HAL_GRGSM_SCANNER_CMD`

Recommended approach:

1. Plug in the SDR dongle and confirm it is detected:

   ```bash
   SoapySDRUtil --find
   ```

2. Test the scanner manually:

   ```bash
   grgsm_scanner -b GSM900 -a 'driver=sdrplay'
   ```

3. Only after confirming output, wire the exact command into the environment
   variable.

## 10. Run The Walking Sweep POC

All stubs on a desktop machine (no hardware required):

```bash
python3 firmware/scripts/sweep_poc.py
```

Real sensors plus mock radio on the Pi:

```bash
HAL_ROTATION=qmc5883l HAL_TILT=mpu6050 HAL_ACCEL=mpu6050 \
HAL_CELLS=mock HAL_TRIGGER_DISTANCE=2.0 \
python3 firmware/scripts/sweep_poc.py
```

This POC:

- tracks relative motion in local metres
- triggers cell reads after walking a configured distance
- is a visualisation and experimentation tool, not the production e-paper flow

Press **Space** for a manual cell measurement trigger.

## 11. Troubleshooting

### Display import fails

Likely cause: the Waveshare submodule is missing.

Fix:

```bash
git submodule update --init --recursive
```

### `lookup_tower()` exits with a CSV error

Likely cause: `firmware/data/<mcc>.csv` is missing on the device.

Fix: sync the required OpenCellID CSV files to the Pi (see step 6).

### Navigation starts at wrong location

Likely cause: `.env.local` is missing or has wrong coordinates.

Fix: create or update `INITIAL_L` in `.env.local` at the repo root.

### Map renders blank placeholders

Likely cause: offline tiles are not downloaded.

Fix:

```bash
python3 firmware/scripts/install_tiles.py
```

### I2C sensor not detected

Likely causes: wiring mistake, I2C not enabled, wrong voltage, wrong address.

Fix:

```bash
i2cdetect -y 1
```

Verify wiring tables in `docs/hardware.md`. Expected addresses: `0x0d` and
`0x68`.

### `grgsm_scanner` path fails

Likely causes: command not installed, SDR driver not configured, SoapySDR
device string incorrect.

Fix: validate the exact command in a shell first, then pass the tested command
to `HAL_GRGSM_SCANNER_CMD`.

### Git pull on Pi fails after initial setup

Likely cause: the pseudoclone step in `setup_pi.sh` was interrupted.

Fix: re-run the setup script, or manually on the Pi:

```bash
cd ~/Tooes
git fetch origin
git checkout -B main origin/main
```

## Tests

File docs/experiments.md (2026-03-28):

# Experiments And Proof-Of-Concepts

This repository contains both product-facing code and experimental utilities.
This document draws the current boundary so the main documentation can stay
clear about what is core and what is exploratory.

## Core Runtime Code

These areas are part of the main project surface today:

- `firmware/hal/`
- `firmware/ui/`
- `firmware/opencellid.py`
- `firmware/run.py`
- `firmware/tests/`
- `scripts/setup_pi.sh`

These files support the Raspberry Pi app, the RF path, and the documented HAL
backends.

## Proof-Of-Concept And Support Scripts

These scripts are useful, but they are better understood as supporting tools or
experiments than as stable product entry points.

### `firmware/scripts/sweep_poc.py`

Purpose:

- walking proof-of-concept for motion tracking plus cell sampling

Status:

- actively meaningful for experimentation
- not the same as the e-paper app

### `firmware/scripts/orientation_cube.py`

Purpose:

- visualize sensor orientation on a Pi desktop

Status:

- calibration and debugging aid
- not part of the main end-user flow

### `firmware/scripts/install_tiles.py`

Purpose:

- preload offline map tiles for the map renderer

Status:

- operational utility
- required only if you want real offline tiles instead of placeholders

## `separate_component_files/`

The `separate_component_files/` directory should currently be treated as
experimental and component-specific.

Contents include:

- `hardcoded_PoC_display_ink.py`
- `mpu6050_accel_logger.py`
- `plot_mpu6050_imu_log.py`
- `plot_mpu6050_relative_path.py`

These files are valuable because they preserve experiments and one-off
validation work, but they should not be confused with the supported project API
or the primary runtime path.

## Why This Boundary Matters

Keeping experiments explicitly labeled has two benefits:

1. the project docs can stay honest about what a new developer or judge should
   run first
2. the exploratory work remains documented without being mistaken for stable
   product behavior

## Recommended Documentation Rule

When a file is experimental, document it in terms of:

- what question it helped answer
- what hardware or data it assumes
- whether its results have been folded into the main firmware path

When a file is core, document it in terms of:

- public behavior
- configuration
- algorithmic assumptions
- runtime dependencies

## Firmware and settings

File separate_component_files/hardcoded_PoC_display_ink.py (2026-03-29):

#!/usr/bin/env python3
import math
import logging
import sys
import time
from pathlib import Path

from PIL import Image, ImageDraw, ImageFont
from gpiozero import RotaryEncoder, Button

BASE_DIR = Path(__file__).resolve().parent
REPO_ROOT = BASE_DIR.parent
WAVESHARE_LIB = (
    REPO_ROOT
    / "external"
    / "waveshare-epd"
    / "RaspberryPi_JetsonNano"
    / "python"
    / "lib"
)
TILE_ROOT = REPO_ROOT / "firmware" / "offline_tiles"

if not WAVESHARE_LIB.exists():
    raise FileNotFoundError(
        f"Waveshare lib not found: {WAVESHARE_LIB}\n"
        "From repo root run:\n"
        "  git submodule update --init --recursive"
    )

if str(WAVESHARE_LIB) not in sys.path:
    sys.path.insert(0, str(WAVESHARE_LIB))

from waveshare_epd import epd2in9_V2

logging.basicConfig(level=logging.INFO)

# =========================================================
# Display settings - LANDSCAPE
# =========================================================
EPD_WIDTH = 296
EPD_HEIGHT = 128

# =========================================================
# Map / location settings
# USER is always the map center
# =========================================================
USER_LAT = 42.012280
USER_LON = 23.095261

TOWER_LAT = 42.0140
TOWER_LON = 23.0942

MIN_ZOOM = 0
MAX_ZOOM = 19
DEFAULT_ZOOM = 16

TILE_SIZE = 256

# =========================================================
# HW-040 pins (BCM)
# board pin 29 = GPIO5
# board pin 31 = GPIO6
# board pin 33 = GPIO13
# =========================================================
ENCODER_CLK_PIN = 5
ENCODER_DT_PIN = 6
ENCODER_SW_PIN = 13

# =========================================================
# Drawing settings
# =========================================================
USER_RADIUS = 5
USER_STROKE = 2

TOWER_STROKE = 3
TOWER_BODY_W = 10
TOWER_BODY_H = 16

SIGNAL_STROKE = 3
SIGNAL_RADII = [12, 18, 24]

LINK_STROKE = 2
EDGE_ARROW_STROKE = 3
EDGE_ARROW_LEN = 14
EDGE_ARROW_WING = 6

font = ImageFont.load_default()

# =========================================================
# Globals
# =========================================================
current_zoom = DEFAULT_ZOOM
show_overlay = False
needs_redraw = True
encoder = None


def clamp(value, min_value, max_value):
    return max(min_value, min(value, max_value))


# =========================================================
# Coordinate helpers
# =========================================================
def latlon_to_world_pixels(lat, lon, zoom):
    lat = clamp(lat, -85.05112878, 85.05112878)
    scale = TILE_SIZE * (2 ** zoom)

    x = (lon + 180.0) / 360.0 * scale
    lat_rad = math.radians(lat)
    y = (1.0 - math.log(math.tan(lat_rad) + 1 / math.cos(lat_rad)) / math.pi) / 2.0 * scale
    return x, y


def latlon_to_screen(lat, lon, center_lat, center_lon, zoom, width, height):
    center_x_world, center_y_world = latlon_to_world_pixels(center_lat, center_lon, zoom)
    point_x_world, point_y_world = latlon_to_world_pixels(lat, lon, zoom)

    sx = (point_x_world - center_x_world) + (width / 2)
    sy = (point_y_world - center_y_world) + (height / 2)
    return sx, sy


def bearing_degrees(lat1, lon1, lat2, lon2):
    phi1 = math.radians(lat1)
    phi2 = math.radians(lat2)
    dlon = math.radians(lon2 - lon1)

    y = math.sin(dlon) * math.cos(phi2)
    x = math.cos(phi1) * math.sin(phi2) - math.sin(phi1) * math.cos(phi2) * math.cos(dlon)

    angle = math.degrees(math.atan2(y, x))
    return (angle + 360) % 360


def bearing_to_unit_vector(deg):
    rad = math.radians(deg)
    dx = math.sin(rad)
    dy = -math.cos(rad)
    return dx, dy


def bearing_to_text(deg):
    directions = ["N", "NE", "E", "SE", "S", "SW", "W", "NW"]
    idx = int((deg + 22.5) // 45) % 8
    return directions[idx]


# =========================================================
# Tile loading - OFFLINE ONLY
# =========================================================
def make_missing_tile(z, x, y):
    img = Image.new("L", (TILE_SIZE, TILE_SIZE), 255)
    draw = ImageDraw.Draw(img)
    draw.rectangle((0, 0, TILE_SIZE - 1, TILE_SIZE - 1), outline=0)
    draw.text((8, 8), f"{z}/{x}/{y}", font=font, fill=0)
    draw.text((8, 22), "no tile", font=font, fill=0)
    return img


def fetch_tile(z, x, y):
    n = 2 ** z
    x = x % n

    if y < 0 or y >= n:
        return Image.new("L", (TILE_SIZE, TILE_SIZE), 255)

    tile_path = TILE_ROOT / str(z) / str(x) / f"{y}.png"

    if tile_path.exists():
        try:
            return Image.open(tile_path).convert("L")
        except Exception as e:
            logging.warning(f"Failed reading tile {tile_path}: {e}")

    return make_missing_tile(z, x, y)


def render_map(center_lat, center_lon, zoom, width, height):
    zoom = clamp(zoom, MIN_ZOOM, MAX_ZOOM)

    center_world_x, center_world_y = latlon_to_world_pixels(center_lat, center_lon, zoom)

    left_world = center_world_x - width / 2
    top_world = center_world_y - height / 2
    right_world = center_world_x + width / 2
    bottom_world = center_world_y + height / 2

    left_tile = int(math.floor(left_world / TILE_SIZE))
    right_tile = int(math.floor(right_world / TILE_SIZE))
    top_tile = int(math.floor(top_world / TILE_SIZE))
    bottom_tile = int(math.floor(bottom_world / TILE_SIZE))

    canvas = Image.new("L", (width, height), 255)

    for ty in range(top_tile, bottom_tile + 1):
        for tx in range(left_tile, right_tile + 1):
            tile = fetch_tile(zoom, tx, ty)
            paste_x = int(tx * TILE_SIZE - left_world)
            paste_y = int(ty * TILE_SIZE - top_world)
            canvas.paste(tile, (paste_x, paste_y))

    draw = ImageDraw.Draw(canvas)
    draw.rectangle((0, 0, width - 1, height - 1), outline=0)
    draw.rectangle((0, 0, width - 1, 12), fill=255)
    draw.text((4, 2), f"Offline Z:{zoom}", font=font, fill=0)

    if show_overlay:
        draw.text((214, 2), "SIG ON", font=font, fill=0)
    else:
        draw.text((210, 2), "SIG OFF", font=font, fill=0)

    return canvas


# =========================================================
# Drawing helpers
# =========================================================
def point_visible(x, y, width, height, margin_top=12, margin=0):
    return (margin <= x < width - margin) and (margin_top <= y < height - margin)


def draw_user_marker(draw, x, y):
    r = USER_RADIUS
    draw.ellipse((x - r, y - r, x + r, y + r), outline=0, width=USER_STROKE, fill=255)
    draw.line((x - 8, y, x + 8, y), fill=0, width=USER_STROKE)
    draw.line((x, y - 8, x, y + 8), fill=0, width=USER_STROKE)
    draw.text((x + 8, y + 6), "YOU", font=font, fill=0)


def draw_tower_icon(draw, x, y):
    body_w = TOWER_BODY_W
    body_h = TOWER_BODY_H
    top_y = y - body_h // 2
    bottom_y = y + body_h // 2

    draw.line((x - body_w // 2, bottom_y, x, top_y), fill=0, width=TOWER_STROKE)
    draw.line((x + body_w // 2, bottom_y, x, top_y), fill=0, width=TOWER_STROKE)
    draw.line((x - body_w // 2 - 2, bottom_y, x + body_w // 2 + 2, bottom_y), fill=0, width=TOWER_STROKE)
    draw.line((x - body_w // 3, y + 3, x + body_w // 3, y + 3), fill=0, width=2)
    draw.line((x - body_w // 4, y - 2, x + body_w // 4, y - 2), fill=0, width=2)
    draw.line((x, top_y - 4, x, top_y + 2), fill=0, width=TOWER_STROKE)

    arc_r1 = 7
    arc_r2 = 11
    cx = x
    cy = top_y - 4
    draw.arc((cx - arc_r1, cy - arc_r1, cx + arc_r1, cy + arc_r1), 300, 60, fill=0, width=2)
    draw.arc((cx - arc_r2, cy - arc_r2, cx + arc_r2, cy + arc_r2), 300, 60, fill=0, width=2)

    draw.text((x + 8, y + 6), "TWR", font=font, fill=0)


def draw_signal_from_user(draw, x, y, bearing_deg):
    pil_angle = (bearing_deg - 90) % 360

    spread = 35
    start = pil_angle - spread
    end = pil_angle + spread

    draw.ellipse((x - 2, y - 2, x + 2, y + 2), fill=0)

    for radius in SIGNAL_RADII:
        draw.arc(
            (x - radius, y - radius, x + radius, y + radius),
            start=start,
            end=end,
            fill=0,
            width=SIGNAL_STROKE
        )


def draw_link_line(draw, x1, y1, x2, y2):
    draw.line((x1, y1, x2, y2), fill=0, width=LINK_STROKE)


def draw_edge_arrow(draw, width, height, bearing_deg, label):
    dx, dy = bearing_to_unit_vector(bearing_deg)

    margin = 12
    top_margin = 18
    cx = width / 2
    cy = height / 2
    candidates = []

    if dx != 0:
        t_left = (margin - cx) / dx
        t_right = ((width - margin) - cx) / dx

        if t_left > 0:
            y = cy + t_left * dy
            if top_margin <= y <= height - margin:
                candidates.append((t_left, margin, y))

        if t_right > 0:
            y = cy + t_right * dy
            if top_margin <= y <= height - margin:
                candidates.append((t_right, width - margin, y))

    if dy != 0:
        t_top = (top_margin - cy) / dy
        t_bottom = ((height - margin) - cy) / dy

        if t_top > 0:
            x = cx + t_top * dx
            if margin <= x <= width - margin:
                candidates.append((t_top, x, top_margin))

        if t_bottom > 0:
            x = cx + t_bottom * dx
            if margin <= x <= width - margin:
                candidates.append((t_bottom, x, height - margin))

    if not candidates:
        return

    _, px, py = min(candidates, key=lambda item: item[0])

    back_x = px - dx * EDGE_ARROW_LEN
    back_y = py - dy * EDGE_ARROW_LEN

    perp_x = -dy
    perp_y = dx

    left_x = back_x + perp_x * EDGE_ARROW_WING
    left_y = back_y + perp_y * EDGE_ARROW_WING
    right_x = back_x - perp_x * EDGE_ARROW_WING
    right_y = back_y - perp_y * EDGE_ARROW_WING

    draw.line((back_x, back_y, px, py), fill=0, width=EDGE_ARROW_STROKE)
    draw.line((left_x, left_y, px, py), fill=0, width=EDGE_ARROW_STROKE)
    draw.line((right_x, right_y, px, py), fill=0, width=EDGE_ARROW_STROKE)

    tx = max(2, min(width - 28, px - 8))
    ty = max(14, min(height - 10, py - 10))
    draw.text((tx, ty), label, font=font, fill=0)


# =========================================================
# Overlay drawing
# =========================================================
def draw_overlay(img, center_lat, center_lon, zoom):
    draw = ImageDraw.Draw(img)
    w, h = img.size

    user_x = w / 2
    user_y = h / 2

    tower_x, tower_y = latlon_to_screen(TOWER_LAT, TOWER_LON, center_lat, center_lon, zoom, w, h)

    tower_visible = point_visible(tower_x, tower_y, w, h, margin_top=12)
    tower_bearing_from_user = bearing_degrees(USER_LAT, USER_LON, TOWER_LAT, TOWER_LON)
    tower_bearing_from_center = bearing_degrees(center_lat, center_lon, TOWER_LAT, TOWER_LON)

    draw_user_marker(draw, user_x, user_y)
    draw_signal_from_user(draw, user_x, user_y, tower_bearing_from_user)

    if tower_visible:
        draw_tower_icon(draw, tower_x, tower_y)
        draw_link_line(draw, user_x, user_y, tower_x, tower_y)
    else:
        draw_edge_arrow(draw, w, h, tower_bearing_from_center, "TWR")

    draw.rectangle((100, 0, 208, 12), fill=255)
    draw.text((102, 2), f"DIR:{bearing_to_text(tower_bearing_from_user)}", font=font, fill=0)

    return img


# =========================================================
# Controls
# =========================================================
def zoom_from_steps():
    return clamp(DEFAULT_ZOOM + encoder.steps, MIN_ZOOM, MAX_ZOOM)


def on_button_press():
    global show_overlay, needs_redraw
    show_overlay = not show_overlay
    logging.info(f"show_overlay={show_overlay}")
    needs_redraw = True


# =========================================================
# Main
# =========================================================
def main():
    global encoder, current_zoom, needs_redraw

    if not TILE_ROOT.exists():
        logging.warning(f"Offline tile folder not found: {TILE_ROOT}")

    encoder = RotaryEncoder(
        a=ENCODER_CLK_PIN,
        b=ENCODER_DT_PIN,
        wrap=False
    )
    encoder.steps = 0

    button = Button(ENCODER_SW_PIN, pull_up=True, bounce_time=0.2)
    button.when_pressed = on_button_press

    epd = epd2in9_V2.EPD()
    logging.info("Initializing display...")
    epd.init()
    epd.Clear(0xFF)

    current_zoom = DEFAULT_ZOOM
    needs_redraw = True

    try:
        while True:
            new_zoom = zoom_from_steps()

            if new_zoom != current_zoom:
                current_zoom = new_zoom
                needs_redraw = True

                if current_zoom == MIN_ZOOM and encoder.steps < (MIN_ZOOM - DEFAULT_ZOOM):
                    encoder.steps = MIN_ZOOM - DEFAULT_ZOOM
                elif current_zoom == MAX_ZOOM and encoder.steps > (MAX_ZOOM - DEFAULT_ZOOM):
                    encoder.steps = MAX_ZOOM - DEFAULT_ZOOM

            if needs_redraw:
                logging.info(f"Rendering zoom={current_zoom}, show_overlay={show_overlay}")

                img = render_map(
                    USER_LAT,
                    USER_LON,
                    current_zoom,
                    EPD_WIDTH,
                    EPD_HEIGHT
                )

                if show_overlay:
                    img = draw_overlay(
                        img,
                        USER_LAT,
                        USER_LON,
                        current_zoom
                    )

                epd.display(epd.getbuffer(img))
                needs_redraw = False

            time.sleep(0.05)

    except KeyboardInterrupt:
        logging.info("Exiting...")

    finally:
        try:
            epd.sleep()
        except Exception as e:
            logging.warning(f"epd.sleep() failed: {e}")


if __name__ == "__main__":
    main()

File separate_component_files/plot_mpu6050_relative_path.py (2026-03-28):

#!/usr/bin/env python3
"""Estimate and plot a relative 2D path from MPU-6050 IMU logs.

This script does not recover a true ground-truth path. It produces a first-pass
dead-reckoning estimate by:
1. detecting likely steps from linear acceleration magnitude
2. using one integrated gyro angle axis as the relative heading
3. advancing a fixed step length in that heading

That makes it useful for visualizing relative movement around the start point,
but it will drift and depends heavily on sensor mounting.

Examples:
    python3 separate_component_files/plot_mpu6050_relative_path.py
    python3 separate_component_files/plot_mpu6050_relative_path.py my_log.csv --show
    python3 separate_component_files/plot_mpu6050_relative_path.py my_log.csv --heading-axis z
"""

from __future__ import annotations

import argparse
import csv
import math
import statistics
from dataclasses import dataclass
from pathlib import Path


_DEFAULT_LOG_DIR = Path(__file__).resolve().parent / "logs"


@dataclass
class ImuPathInput:
    time_s: list[float]
    linear_mag_g: list[float]
    stationary: list[bool]
    angle_x_deg: list[float]
    angle_y_deg: list[float]
    angle_z_deg: list[float]


@dataclass
class PathEstimate:
    heading_axis: str
    threshold_g: float
    step_indices: list[int]
    step_times_s: list[float]
    step_headings_deg: list[float]
    step_peaks_g: list[float]
    x_m: list[float]
    y_m: list[float]


def _parse_args() -> argparse.Namespace:
    parser = argparse.ArgumentParser(
        description="Estimate a relative 2D path from an MPU-6050 IMU CSV log."
    )
    parser.add_argument(
        "input",
        nargs="?",
        type=Path,
        default=None,
        help="Path to the CSV log. Defaults to the latest file in separate_component_files/logs/.",
    )
    parser.add_argument(
        "--output",
        type=Path,
        default=None,
        help="PNG output path. Defaults next to the CSV with a _path suffix.",
    )
    parser.add_argument(
        "--show",
        action="store_true",
        help="Open the plot interactively after saving.",
    )
    parser.add_argument(
        "--heading-axis",
        choices=("auto", "x", "y", "z"),
        default="auto",
        help="Which integrated gyro angle to treat as heading.",
    )
    parser.add_argument(
        "--invert-heading",
        action="store_true",
        help="Flip the heading sign if the path comes out mirrored.",
    )
    parser.add_argument(
        "--heading-offset-deg",
        type=float,
        default=0.0,
        help="Rotate the whole path by a fixed offset in degrees.",
    )
    parser.add_argument(
        "--step-length-m",
        type=float,
        default=0.70,
        help="Assumed step length in meters.",
    )
    parser.add_argument(
        "--min-step-seconds",
        type=float,
        default=0.35,
        help="Minimum time between detected steps.",
    )
    parser.add_argument(
        "--peak-threshold-g",
        type=float,
        default=None,
        help="Manual threshold for linear acceleration peaks. If omitted, auto-estimated.",
    )
    parser.add_argument(
        "--start-seconds",
        type=float,
        default=None,
        help="Optional lower bound for elapsed time.",
    )
    parser.add_argument(
        "--end-seconds",
        type=float,
        default=None,
        help="Optional upper bound for elapsed time.",
    )
    args = parser.parse_args()

    if args.step_length_m <= 0:
        parser.error("--step-length-m must be > 0")
    if args.min_step_seconds <= 0:
        parser.error("--min-step-seconds must be > 0")
    if args.peak_threshold_g is not None and args.peak_threshold_g <= 0:
        parser.error("--peak-threshold-g must be > 0 when provided")

    return args


def _latest_log_path() -> Path:
    candidates = sorted(_DEFAULT_LOG_DIR.glob("*.csv"))
    if not candidates:
        raise FileNotFoundError(
            f"No CSV logs found in {_DEFAULT_LOG_DIR}. Pass a CSV path explicitly."
        )
    return candidates[-1]


def _float(row: dict[str, str], key: str) -> float:
    return float(row[key])


def _bool(row: dict[str, str], key: str) -> bool:
    return bool(int(row[key]))


def _load_input(
    path: Path,
    start_seconds: float | None,
    end_seconds: float | None,
) -> ImuPathInput:
    time_s: list[float] = []
    linear_mag_g: list[float] = []
    stationary: list[bool] = []
    angle_x_deg: list[float] = []
    angle_y_deg: list[float] = []
    angle_z_deg: list[float] = []

    with path.open("r", newline="", encoding="utf-8") as handle:
        reader = csv.DictReader(handle)
        for row in reader:
            elapsed = _float(row, "elapsed_s")
            if start_seconds is not None and elapsed < start_seconds:
                continue
            if end_seconds is not None and elapsed > end_seconds:
                continue

            time_s.append(elapsed)
            linear_mag_g.append(_float(row, "linear_avg_mag_g"))
            stationary.append(_bool(row, "stationary"))
            angle_x_deg.append(_float(row, "gyro_angle_x_deg"))
            angle_y_deg.append(_float(row, "gyro_angle_y_deg"))
            angle_z_deg.append(_float(row, "gyro_angle_z_deg"))

    if not time_s:
        raise ValueError("The selected CSV has no rows in the requested time window.")

    return ImuPathInput(
        time_s=time_s,
        linear_mag_g=linear_mag_g,
        stationary=stationary,
        angle_x_deg=angle_x_deg,
        angle_y_deg=angle_y_deg,
        angle_z_deg=angle_z_deg,
    )


def _choose_heading_axis(data: ImuPathInput, mode: str) -> str:
    if mode != "auto":
        return mode

    active_indices = [i for i, is_stationary in enumerate(data.stationary) if not is_stationary]
    if not active_indices:
        active_indices = list(range(len(data.time_s)))

    axis_to_values = {
        "x": [data.angle_x_deg[i] for i in active_indices],
        "y": [data.angle_y_deg[i] for i in active_indices],
        "z": [data.angle_z_deg[i] for i in active_indices],
    }
    axis_ranges = {
        axis: (max(values) - min(values)) if values else 0.0
        for axis, values in axis_to_values.items()
    }
    return max(axis_ranges, key=axis_ranges.get)


def _heading_series(data: ImuPathInput, axis: str) -> list[float]:
    if axis == "x":
        return data.angle_x_deg
    if axis == "y":
        return data.angle_y_deg
    return data.angle_z_deg


def _auto_peak_threshold(data: ImuPathInput) -> float:
    stationary_values = [
        value
        for value, is_stationary in zip(data.linear_mag_g, data.stationary)
        if is_stationary
    ]
    if stationary_values:
        mean = statistics.fmean(stationary_values)
        std = statistics.pstdev(stationary_values) if len(stationary_values) > 1 else 0.0
        return max(0.02, mean + (4.0 * std))

    return max(0.02, statistics.fmean(data.linear_mag_g) * 2.5)
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

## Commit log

2026-03-28 Add Waveshare submodule and fix offline tile paths
    [hardcoded_PoC_display_ink.py]
2026-03-28 implemented qmc5883l sensor in HAL
2026-03-28 fix: bigger tutorial text, trimmed for e-paper fit
    [screens.py]
2026-03-28 3D models of the hardware added
    [COMPONENTSPLATE.stl, SCROLL.stl, TOOESHANDLE.stl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]
2026-03-28 Add MPU-6050 IMU logger with gyro bias calibration
2026-03-28 Add MPU-6050 IMU log plotting script
2026-03-28 Add relative path plotter for MPU-6050 IMU logs
2026-03-28 Improve IMU path estimation with turn-aware yaw heading
2026-03-28 Add automatic turn snapping to relative path plotting
    [plot_mpu6050_relative_path.py]
2026-03-28 Revert relative path plotter to simpler heading-axis logic
    [plot_mpu6050_relative_path.py]
2026-03-28 Improve IMU path estimation with drift-aware heading
    [plot_mpu6050_relative_path.py]
2026-03-28 Revert path estimator to simple gyro heading model
    [plot_mpu6050_relative_path.py]
2026-03-28 feat: clamp zoom to downloaded tile range, viewport-aware tile download
2026-03-29 Integrate IMU-SDR navigation and trace history
2026-03-29 Add persistent path logging for fused navigation trace
2026-03-29 Refactor UI runtime and make navigation state thread-safe
2026-03-29 Enable trace overlay by default
